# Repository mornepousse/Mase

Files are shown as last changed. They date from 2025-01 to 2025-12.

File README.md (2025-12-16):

# Mase
 Custom esp32 mouse.
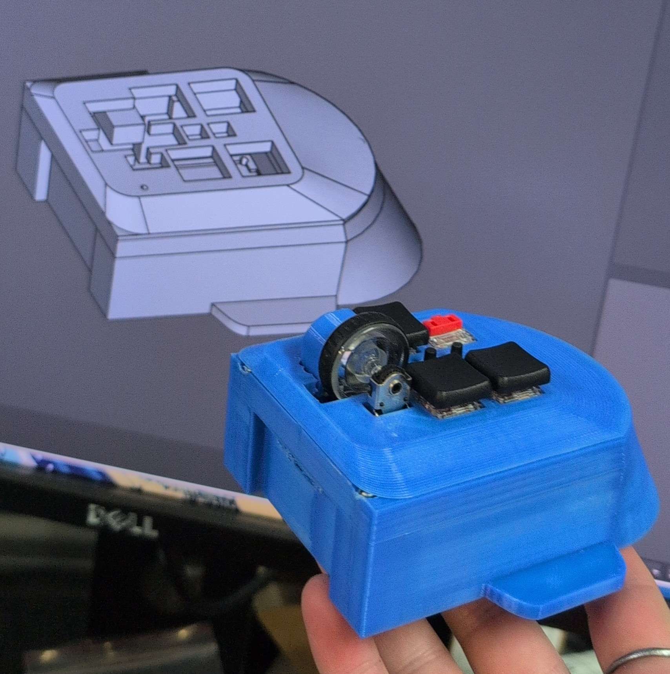
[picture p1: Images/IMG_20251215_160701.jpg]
Front PCB
 
 |index|References|Value|Footprint|Quantity|
 |:-|:--------|:-|:--|:-|
|1| C101, C102, C106, C108, C110    |0.1u|C_0805_2012Metric|5|
|2| C103, C105, C107, C109, C111    |1u|C_0805_2012Metric|5|
|3| C104                            |4.7u|C_0805_2012Metric     |1|
|4| R102, R103, R104                |10k|R_0805_2012Metric|3|
|5| R107, R108, R109                |?|R_0805_2012Metric|3|
|6| R105, R106                      |R_1206|R_0805_2012Metric|2|
|7| R101|39|R_0805_2012Metric|1|
|8| D101, D102|LED_3mm|LED_D3.0mm|2|
|9| U1|ESP32-S3-WROOM-1|ESP32-S3-WROOM-1|1|
|10|U2|PMW3360|PMW3360|1|
|11|U4|	TLV73333PDBV|	SOT-23-5	|1|
|12|U103|	TCR2EF19|	SOT-23-5	|1|
|13|SW1, SW2|	Push_Button|	SW_Hotswap_Kailh_Choc_V1V2_1.00u	|2|
|14|SW101, SW104|	Push_Button|	SW_Micro_Switch	|2|
|15|SW103, SW106|	Push_Button|	SW_Push_1P1T_NO_CK_KSC7xxJ	|2|
|16|SW3|	RotaryEncoder_Switch_MP|	RollerEncoder_Panasonic_EVQWGD001	|1|
|17|	SW102|	Push_Button|Switch_Toggle_SPDT_SubMini	|1|
|18|TP101, TP102, TP103, TP104, TP105, TP106, TP107|TestPoint|TestPoint_Pad_D1.0mm|7|
|19|	H1, H2, H3, H4|	MountingHole|MountingHole_3.2mm_M3|4|
|20|	Brd101|	SSD1306|	128x64OLED	|1|
|21|	J1|	Conn_01x04|	PinHeader_1x04_P2.54mm_Vertical	|1|
|22|	J2|	Conn_02x04_Counter_Clockwise|IDC-Header_2x04_P2.54mm_Vertical|1|
|23|	J101|	Conn_02x03_Counter_Clockwise|	Harwin_Gecko-G125-FVX0605L0X_2x03_P1.25mm_Vertical	|1|

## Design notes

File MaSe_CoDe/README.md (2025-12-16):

# MaSe - Mouse Sensor Firmware

**MaSe** est un firmware de souris haute performance pour l'ESP32-S3, utilisant le capteur optique PMW3389 et l'interface TinyUSB pour une communication HID rapide.

## 🚀 Fonctionnalités

*   **Capteur PMW3389** : Support complet via SPI avec lecture en mode "Burst" pour une latence minimale.
*   **Polling Rate 1000Hz** : Boucle principale et tick FreeRTOS optimisés pour une réponse à 1ms.
*   **DPI Ajustable** : Cycle entre les niveaux de DPI (400, 800, 1600, 3200, 6400) via un bouton dédié.
*   **Molette de défilement** : Support d'encodeur rotatif.
*   **Boutons Programmables** : Clic gauche, droit, milieu, et touches de fonction (ex: Touche Windows).
*   **Indicateur d'État LED** : LED WS2812 (RGB) pour indiquer le mode de connexion (Vert = USB).
*   **Architecture Modulaire** : Code séparé pour le capteur, la gestion des LEDs et la logique principale.

## 🛠 Matériel Requis

*   **Microcontrôleur** : ESP32-S3 (Testé sur DevKitM-1 / DevKitC).
*   **Capteur** : PixArt PMW3389.
*   **Composants** : Switchs pour les boutons, Encodeur rotatif, LED WS2812.

### 🔌 Pinout (Configuration par défaut)

| Périphérique | Fonction | GPIO (ESP32-S3) |
| :--- | :--- | :--- |
| **PMW3389** | MISO | 7 |
| | MOSI | 6 |
| | SCLK | 5 |
| | CS | 15 |
| | MOTION | 4 |
| **Boutons** | Clic Gauche (LMB) | 21 |
| | Clic Droit (RMB) | 37 |
| | Clic Molette (Middle) | 38 |
| | DPI Switch | 44 |
| | Touche Windows | 35 |
| **Encodeur** | A | 2 |
| | B | 42 |
| | C (Commun/GND) | 41 |
| **LED** | Data (WS2812) | 48 |

## 📂 Structure du Projet

```
main/
├── main.c           # Point d'entrée, boucle principale (USB, lecture capteur)
├── pmw3389.c        # Driver du capteur (SPI, Burst read, SROM)
├── pmw3389.h        # Définitions et prototypes du capteur
├── led_status.c     # Gestion de la LED d'état (RMT)
├── led_status.h     # Prototypes LED
├── srom_pmw3389.h   # Firmware binaire du capteur
└── CMakeLists.txt   # Configuration de build
```

## 🔨 Compilation et Flash

Ce projet utilise le framework **ESP-IDF**.

1.  **Configurer la cible :**
    ```bash
    idf.py set-target esp32s3
    ```

2.  **Compiler :**
    ```bash
    idf.py build
    ```

3.  **Flasher et Monitorer :**
    ```bash
    idf.py -p /dev/ttyACM0 flash monitor
    ```

## 📝 Notes

*   Le firmware du capteur (SROM) est chargé au démarrage. Assurez-vous que le fichier `srom_pmw3389.h` est présent.
*   La fréquence FreeRTOS est configurée à 1000Hz pour assurer la fluidité du curseur.

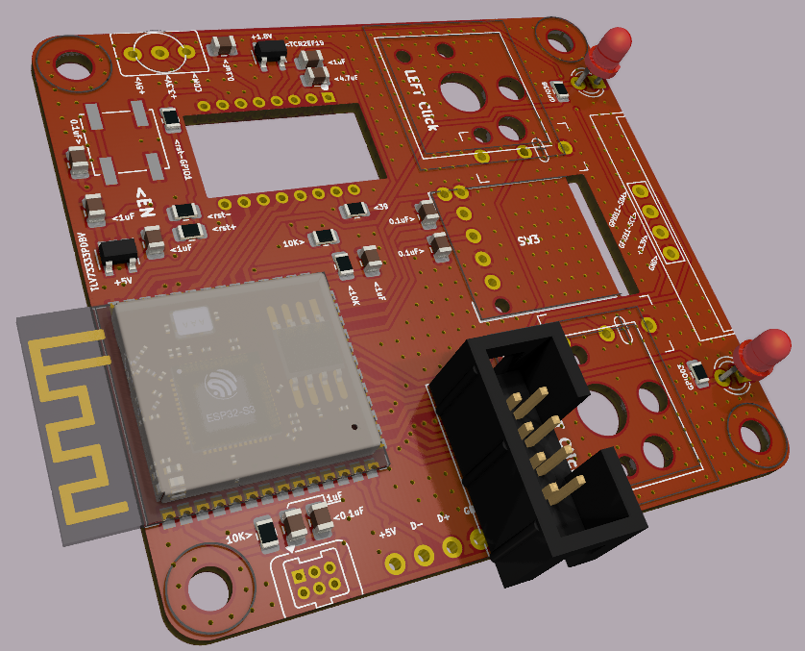
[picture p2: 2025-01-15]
Images/front.png

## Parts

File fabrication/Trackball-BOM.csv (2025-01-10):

Comment | Designator | Footprint | LCSC
0.1u | C11 | Capacitor_SMD:C_0603_1608Metric | C14663
1u | C12 | Capacitor_SMD:C_0603_1608Metric | C15849
4.7u | C14 | Capacitor_SMD:C_0402_1005Metric | C23733
1u | C10,C13,C15,C16 | Capacitor_SMD:C_0402_1005Metric | C52923
30p | C18,C19 | Capacitor_SMD:C_0402_1005Metric | C1570
100n | C1,C2,C3,C4,C5,C6,C7,C8,C9,C17 | Capacitor_SMD:C_0402_1005Metric | C1525
MountingHole | H1,H2,H3,H4 | MountingHole:MountingHole_3.2mm_M3
Conn_01x04 | J1 | Connector_PinHeader_2.54mm:PinHeader_1x04_P2.54mm_Vertical
Conn_02x10_Odd_Even | J2 | Connector_PinHeader_2.54mm:PinHeader_2x10_P2.54mm_Vertical
39 | R1 | Resistor_SMD:R_0402_1005Metric | C25110
27 | R3,R4 | Resistor_SMD:R_0402_1005Metric | C138021
10k | R2,R5 | Resistor_SMD:R_0402_1005Metric | C25744
1k | R6,R7 | Resistor_SMD:R_0402_1005Metric | C11702
SW_Push | SW1,SW2 | Button_Switch_SMD:SW_SPST_Omron_B3FS-100xP | C271750
TCR2EF19 | U1 | Package_TO_SOT_SMD:SOT-23-5 | C146366
PMW3360 | U2 | PMW3360:PMW3360
RP2040 | U3 | RP2040:RP2040-QFN-56 | C2040
TLV73333PDBV | U4 | Package_TO_SOT_SMD:SOT-23-5 | C134139
W25Q128JVS | U5 | Package_SO:SOIC-8_5.23x5.23mm_P1.27mm | C97521
Crystal_GND24 | Y1 | Crystal:Crystal_SMD_3225-4Pin_3.2x2.5mm | C9002

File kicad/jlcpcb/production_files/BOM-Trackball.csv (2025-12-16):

Comment | Designator | Footprint | LCSC | Quantity
TLV73333PDBV | U3 | SOT-23-5 | C134139 | 1
0.1u | C1,C5,C6,C7,C9 | C_0805_2012Metric | C14663 | 5
1u | C2 | C_0805_2012Metric | C15849 | 1
10uF | C8 | C_0805_2012Metric_Pad1.18x1.45mm_HandSolder | C15850 | 1
TP4056 | U5 | SOIC-8-1EP_3.9x4.9mm_P1.27mm_EP2.29x3mm | C16581 | 1
100 | R8 | R_0805_2012Metric_Pad1.20x1.40mm_HandSolder | C17408 | 1
10k | R1,R102,R2,R5 | R_0805_2012Metric | C17414 | 4
1k | R3,R4,R6 | R_0805_2012Metric | C17513 | 3
0R | R7 | R_1206_3216Metric_Pad1.30x1.75mm_HandSolder | C17888 | 1
4.7u | C104 | C_0805_2012Metric | C23733 | 1
39 | R101 | R_0805_2012Metric | C25110 | 1
TCR2EF19 | U1 | SOT-23-5 | C2862411 | 1
DW01 | U6 | SOT-23-6_Handsoldering | C2927799 | 1
1u | C3,C4 | C_0805_2012Metric | C52923 | 2
FS8205A | U7 | SOT-23-6_Handsoldering | C908265 | 1

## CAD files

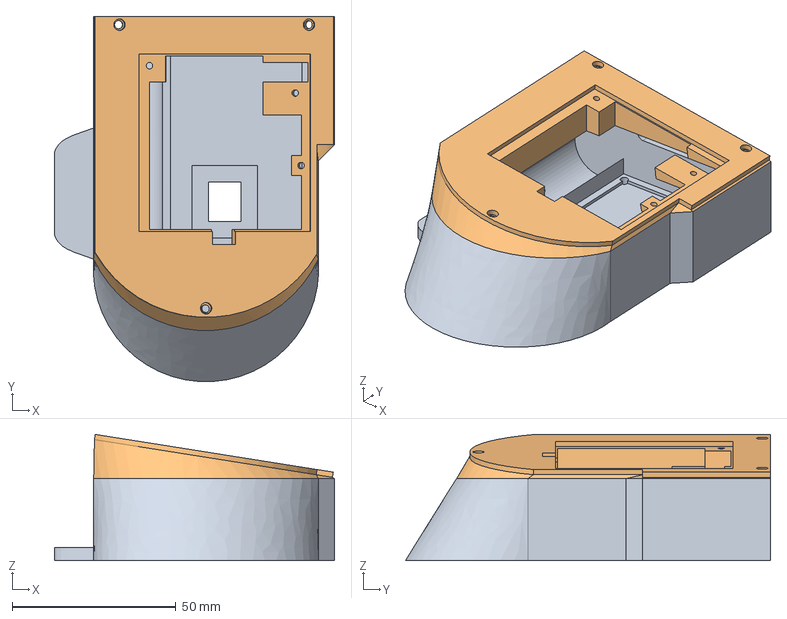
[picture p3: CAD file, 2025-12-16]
fabrication/Unnamed1.FCStd
85.5 x 111.3 x 38.5 mm
Base
supportTopPCB

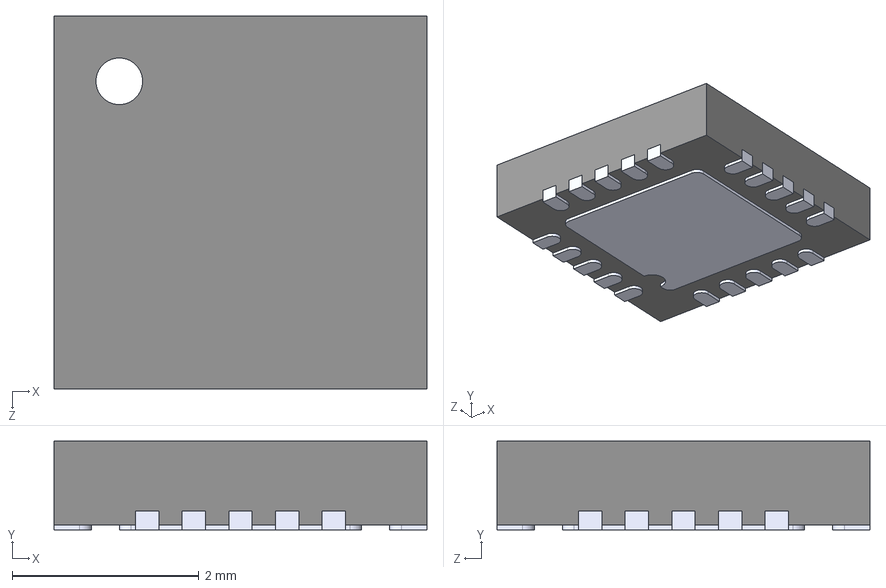
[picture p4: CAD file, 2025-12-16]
kicad/NRF24L01_/NRF24L01_.step
4.00 x 0.95 x 4.00 mm

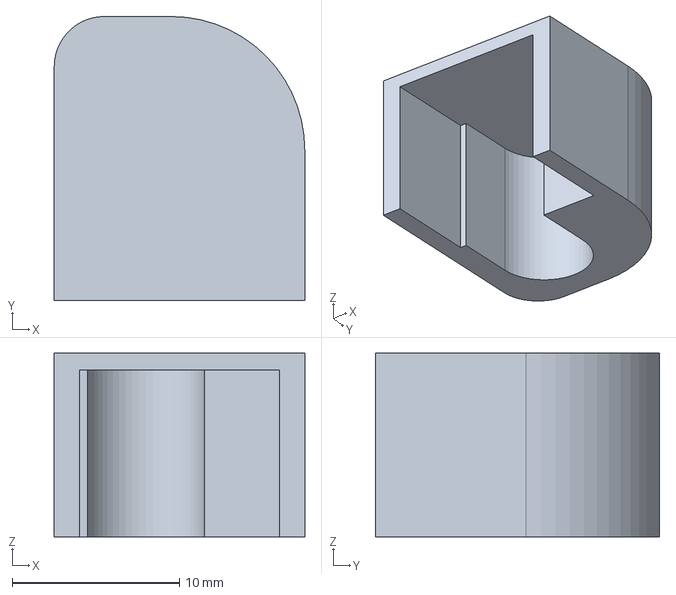
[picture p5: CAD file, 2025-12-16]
fabrication/piecemolette.FCStd
15.0 x 17.0 x 11.0 mm

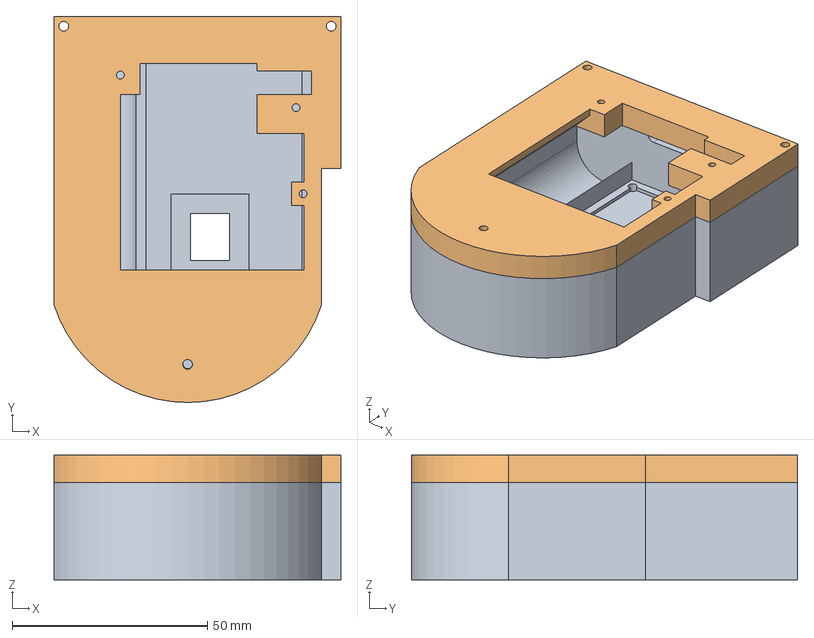
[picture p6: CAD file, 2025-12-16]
fabrication/mase.FCStd
73.5 x 98.9 x 32.0 mm

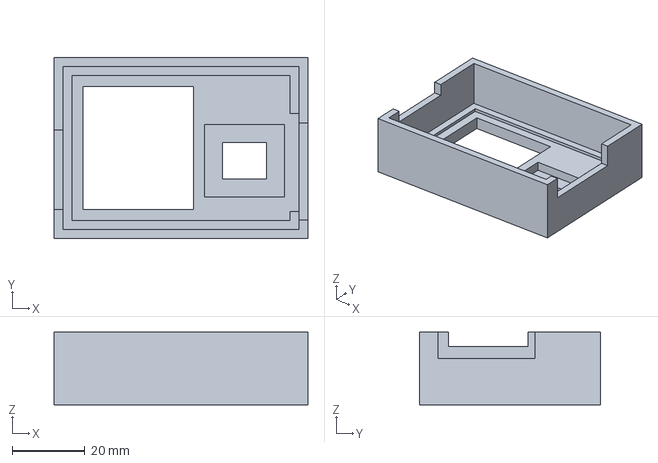
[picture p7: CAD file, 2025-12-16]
fabrication/Unnamed.FCStd
70.0 x 50.0 x 20.0 mm

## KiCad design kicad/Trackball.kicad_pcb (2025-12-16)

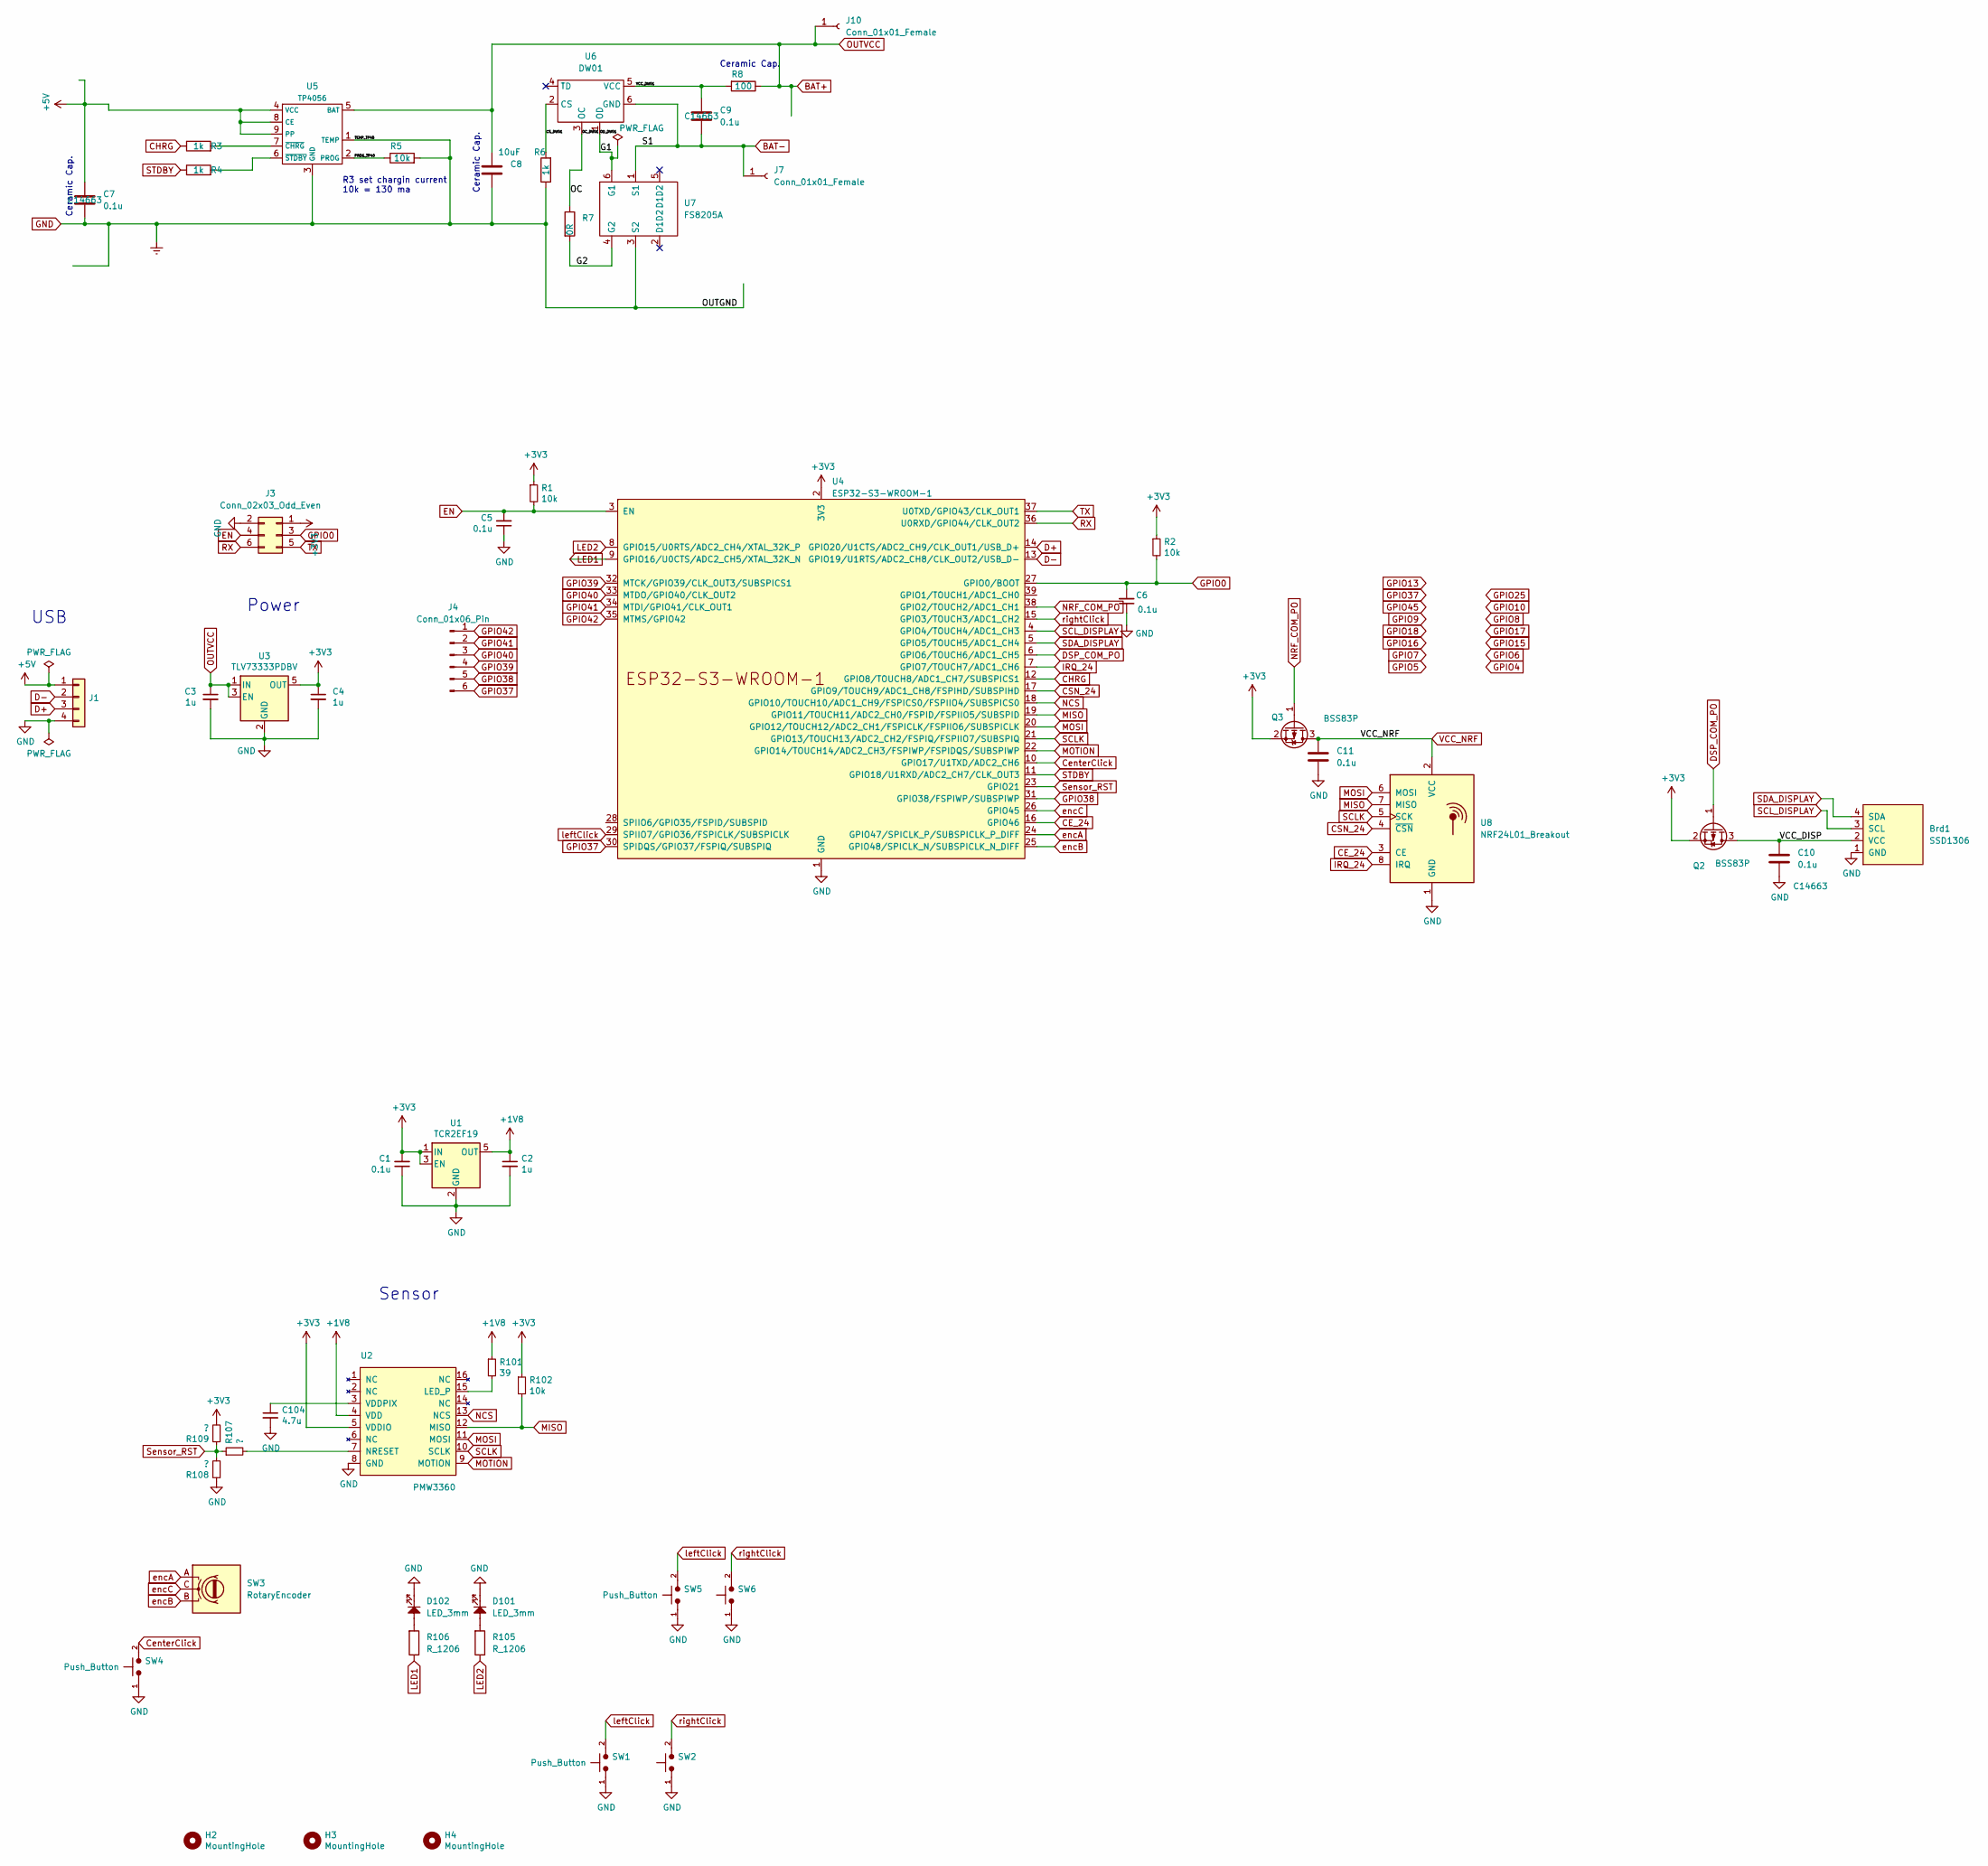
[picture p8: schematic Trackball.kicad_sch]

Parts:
Brd1: SSD1306; PinHeader_1x04_P2.54mm_Vertical
C1, C5, C6, C7, C9, C10, C11: 0.1u; C_0805_2012Metric; LCSC C14663
C2: 1u; C_0805_2012Metric; LCSC C15849
C3, C4: 1u; C_0805_2012Metric; LCSC C52923
C8: 10uF; C_0805_2012Metric_Pad1.18x1.45mm_HandSolder
C104: 4.7u; C_0805_2012Metric; LCSC C23733
D101, D102: LED_3mm; LED_D3.0mm
H2, H3, H4: MountingHole; MountingHole_3.2mm_M3
J1: Conn_01x04; PinHeader_1x04_P2.54mm_Vertical
J3: Conn_02x03_Odd_Even; Harwin_Gecko-G125-FVX0605L0X_2x03_P1.25mm_Vertical
J4: Conn_01x06_Pin; PinHeader_1x06_P2.00mm_Vertical
J7, J10: Conn_01x01_Female; PinSocket_1x01_P2.54mm_Vertical
Q2, Q3: BSS83P; SOT-23
R1, R2, R102: 10k; R_0805_2012Metric; LCSC C25744
R3, R4, R6: 1k; R_0805_2012Metric
R5: 10k; R_0805_2012Metric
R7: 0R; R_1206_3216Metric_Pad1.30x1.75mm_HandSolder
R8: 100; R_0805_2012Metric_Pad1.20x1.40mm_HandSolder
R101: 39; R_0805_2012Metric; LCSC C25110
R105, R106: R_1206; R_0805_2012Metric
R107, R108, R109: ?; R_0805_2012Metric; LCSC C25110
SW1, SW2: Push_Button; SW_Hotswap_Kailh_Choc_V1V2_1.00u
SW3: RotaryEncoder; Alps-EC10E1220501
SW4, SW5, SW6: Push_Button; SW_Micro_Switch
U1: TCR2EF19; SOT-23-5; LCSC C146366
U2: PMW3360
U3: TLV73333PDBV; SOT-23-5; LCSC C134139
U4: ESP32-S3-WROOM-1
U5: TP4056; SOIC-8-1EP_3.9x4.9mm_P1.27mm_EP2.29x3mm
U6: DW01; SOT-23-6_Handsoldering
U7: FS8205A; SOT-23-6_Handsoldering
U8: NRF24L01_Breakout; nRF24L01_Breakout

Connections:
+1V8: C2.1, R101.1, U1.5 (OUT), U2.4 (VDD)
+3V3: C1.2, C4.1, J3.1, Q2.2 (S), Q3.2 (S), R1.1, R2.1, R102.1, R109.2, U1.1 (IN), U1.3 (EN), U2.5 (VDDIO), U3.5 (OUT), U4.2 (3V3)
+5V: C7.1, J1.1, U5.4 (VCC), U5.8 (CE), U5.9 (PP)
/CS_DW01: R6.2, U6.2 (CS)
/G1: U6.1 (OD), U7.6 (G1)
/G2: R7.2, U7.4 (G2)
/OC: R7.1, U6.3 (OC)
/PROG_TP40: R5.1, U5.2 (PROG)
/VCC_DISP: Brd1.2 (VCC), C10.1, Q2.3 (D)
/VCC_DW01: C9.1, R8.2, U6.5 (VCC)
BAT+: C3.1, C8.1, J10.1, R8.1, U3.1 (IN), U3.3 (EN), U5.5 (BAT)
BAT-: C9.2, J7.1, U6.6 (GND), U7.1 (S1)
CE_24: U4.16 (GPIO46), U8.3 (CE)
CHRG: R3.1, U4.12 (GPIO8/TOUCH8/ADC1_CH7/SUBSPICS1)
CSN_24: U4.17 (GPIO9/TOUCH9/ADC1_CH8/FSPIHD/SUBSPIHD), U8.4 (~CSN)
CenterClick: SW4.2, U4.10 (GPIO17/U1TXD/ADC2_CH6)
D+: J1.3, U4.14 (GPIO20/U1CTS/ADC2_CH9/CLK_OUT1/USB_D+)
D-: J1.2, U4.13 (GPIO19/U1RTS/ADC2_CH8/CLK_OUT2/USB_D-)
DSP_COM_PO: Q2.1 (G), U4.6 (GPIO6/TOUCH6/ADC1_CH5)
EN: C5.2, J3.4, R1.2, U4.3 (EN)
GND: Brd1.1 (GND), C1.1, C2.2, C3.2, C4.2, C5.1, C6.1, C7.2, C8.2, C10.2, C11.2, C104.2, D101.1, D102.1, J1.4, J3.2, R5.2, R6.1, R108.1, SW1.1, SW2.1, SW4.1, SW5.1, SW6.1, U1.2 (GND), U2.8 (GND), U3.2 (GND), U4.1 (GND), U4.40 (GND), U4.41 (GND), U5.1 (TEMP), U5.3 (GND), U7.3 (S2), U8.1 (GND)
GPIO0: C6.2, J3.3, R2.2, U4.27 (GPIO0/BOOT)
GPIO37: J4.6, U4.30 (SPIDQS/GPIO37/FSPIQ/SUBSPIQ)
GPIO38: J4.5, U4.31 (GPIO38/FSPIWP/SUBSPIWP)
GPIO39: J4.4, U4.32 (MTCK/GPIO39/CLK_OUT3/SUBSPICS1)
GPIO40: J4.3, U4.33 (MTDO/GPIO40/CLK_OUT2)
GPIO41: J4.2, U4.34 (MTDI/GPIO41/CLK_OUT1)
GPIO42: J4.1, U4.35 (MTMS/GPIO42)
IRQ_24: U4.7 (GPIO7/TOUCH7/ADC1_CH6), U8.8 (IRQ)
LED1: R106.2, U4.9 (GPIO16/U0CTS/ADC2_CH5/XTAL_32K_N)
LED2: R105.2, U4.8 (GPIO15/U0RTS/ADC2_CH4/XTAL_32K_P)
MISO: R102.2, U2.12 (MISO), U4.19 (GPIO11/TOUCH11/ADC2_CH0/FSPID/FSPIIO5/S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), U8.7 (MISO)
MOSI: U2.11 (MOSI), U4.20 (GPIO12/TOUCH12/ADC2_CH1/FSPICLK/FSPIIO6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), U8.6 (MOSI)
MOTION: U2.9 (MOTION), U4.22 (GPIO14/TOUCH14/ADC2_CH3/FSPIWP/FSPIDQS/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)
NCS: U2.13 (NCS), U4.18 (GPIO10/TOUCH10/ADC1_CH9/FSPICS0/FSPIIO4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)
NRF_COM_PO: Q3.1 (G), U4.38 (GPIO2/TOUCH2/ADC1_CH1)
unnamed: D101.2, R105.1
unnamed: D102.2, R106.1
unnamed: R101.2, U2.15 (LED_P)
unnamed: R107.2, U2.7 (NRESET)
unnamed: C104.1, U2.3 (VDDPIX)
unnamed: R3.2, U5.7 (~CHRG)
unnamed: R4.2, U5.6 (~STDBY)
RX: J3.6, U4.36 (U0RXD/GPIO44/CLK_OUT2)
SCLK: U2.10 (SCLK), U4.21 (GPIO13/TOUCH13/ADC2_CH2/FSPIQ/FSPIIO7/S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), U8.5 (SCK)
SCL_DISPLAY: Brd1.3 (SCL), U4.4 (GPIO4/TOUCH4/ADC1_CH3)
SDA_DISPLAY: Brd1.4 (SDA), U4.5 (GPIO5/TOUCH5/ADC1_CH4)
STDBY: R4.1, U4.11 (GPIO18/U1RXD/ADC2_CH7/CLK_OUT3)
Sensor_RST: R107.1, R108.2, R109.1, U4.23 (GPIO21)
TX: J3.5, U4.37 (U0TXD/GPIO43/CLK_OUT1)
VCC_NRF: C11.1, Q3.3 (D), U8.2 (VCC)
encA: SW3.A, U4.24 (GPIO47/SPICLK_P/SUBSPICLK_P_DIFF)
encB: SW3.B, U4.25 (GPIO48/SPICLK_N/SUBSPICLK_N_DIFF)
encC: SW3.C, U4.26 (GPIO45)
leftClick: SW1.2, SW5.2, U4.29 (SPIIO7/GPIO36/FSPICLK/SUBSPICLK)
rightClick: SW2.2, SW6.2, U4.15 (GPIO3/TOUCH3/ADC1_CH2)

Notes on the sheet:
Ceramic Cap.
R3 set chargin current 10k = 130 ma
Power
Sensor
USB

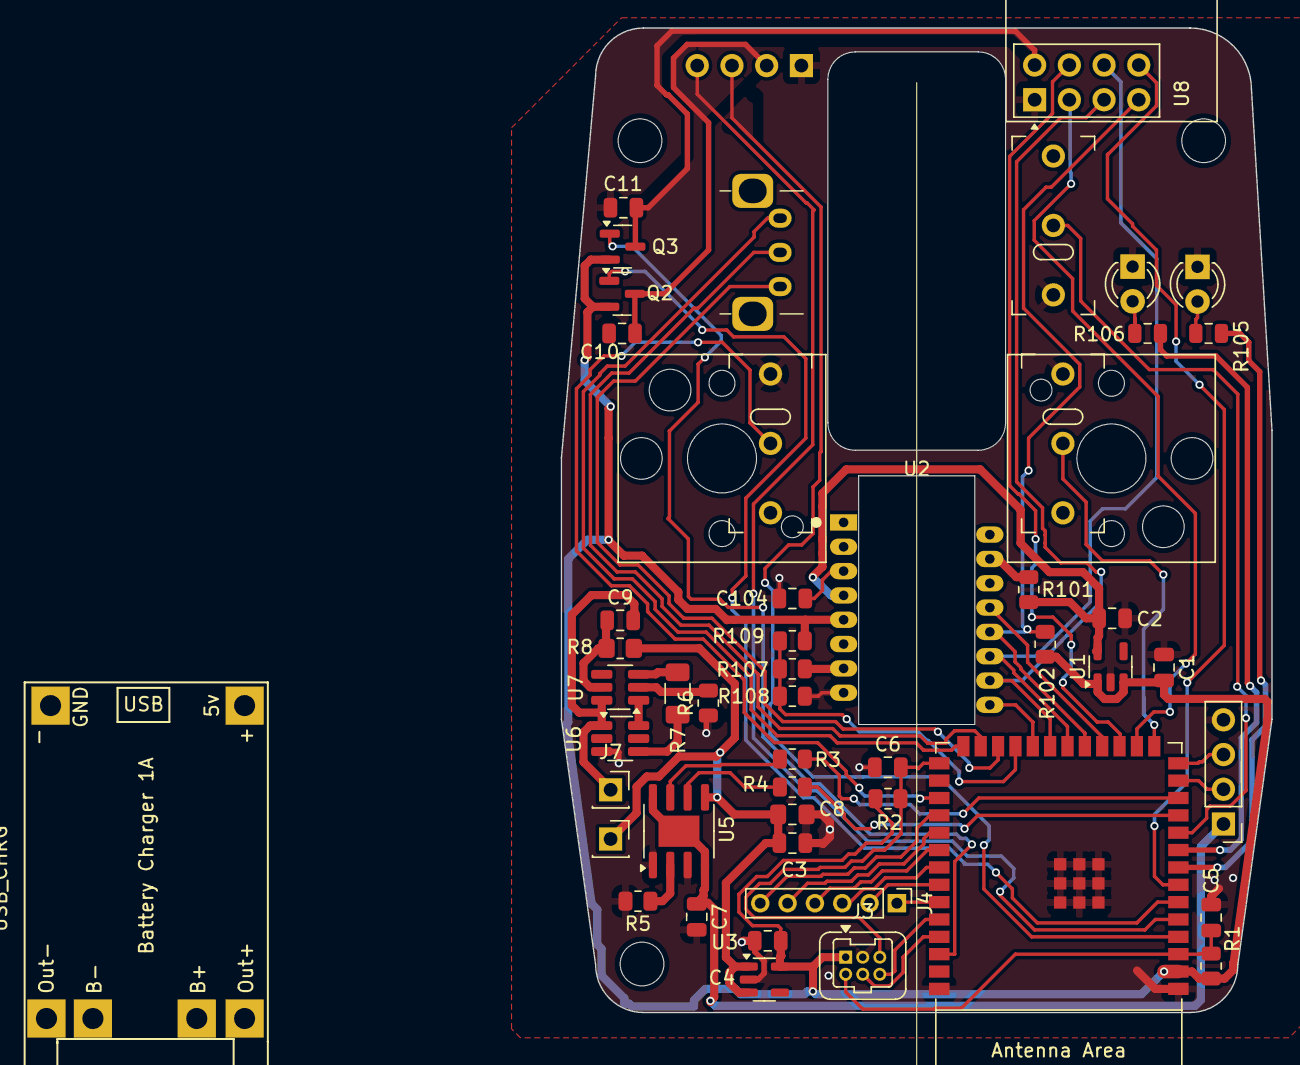
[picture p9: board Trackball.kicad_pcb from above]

Board: 2 copper layers, 52.0 x 72.0 mm, 55 parts (1 on the bottom side), 56 nets.

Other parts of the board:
USB_CHRG**: TP4056-18650

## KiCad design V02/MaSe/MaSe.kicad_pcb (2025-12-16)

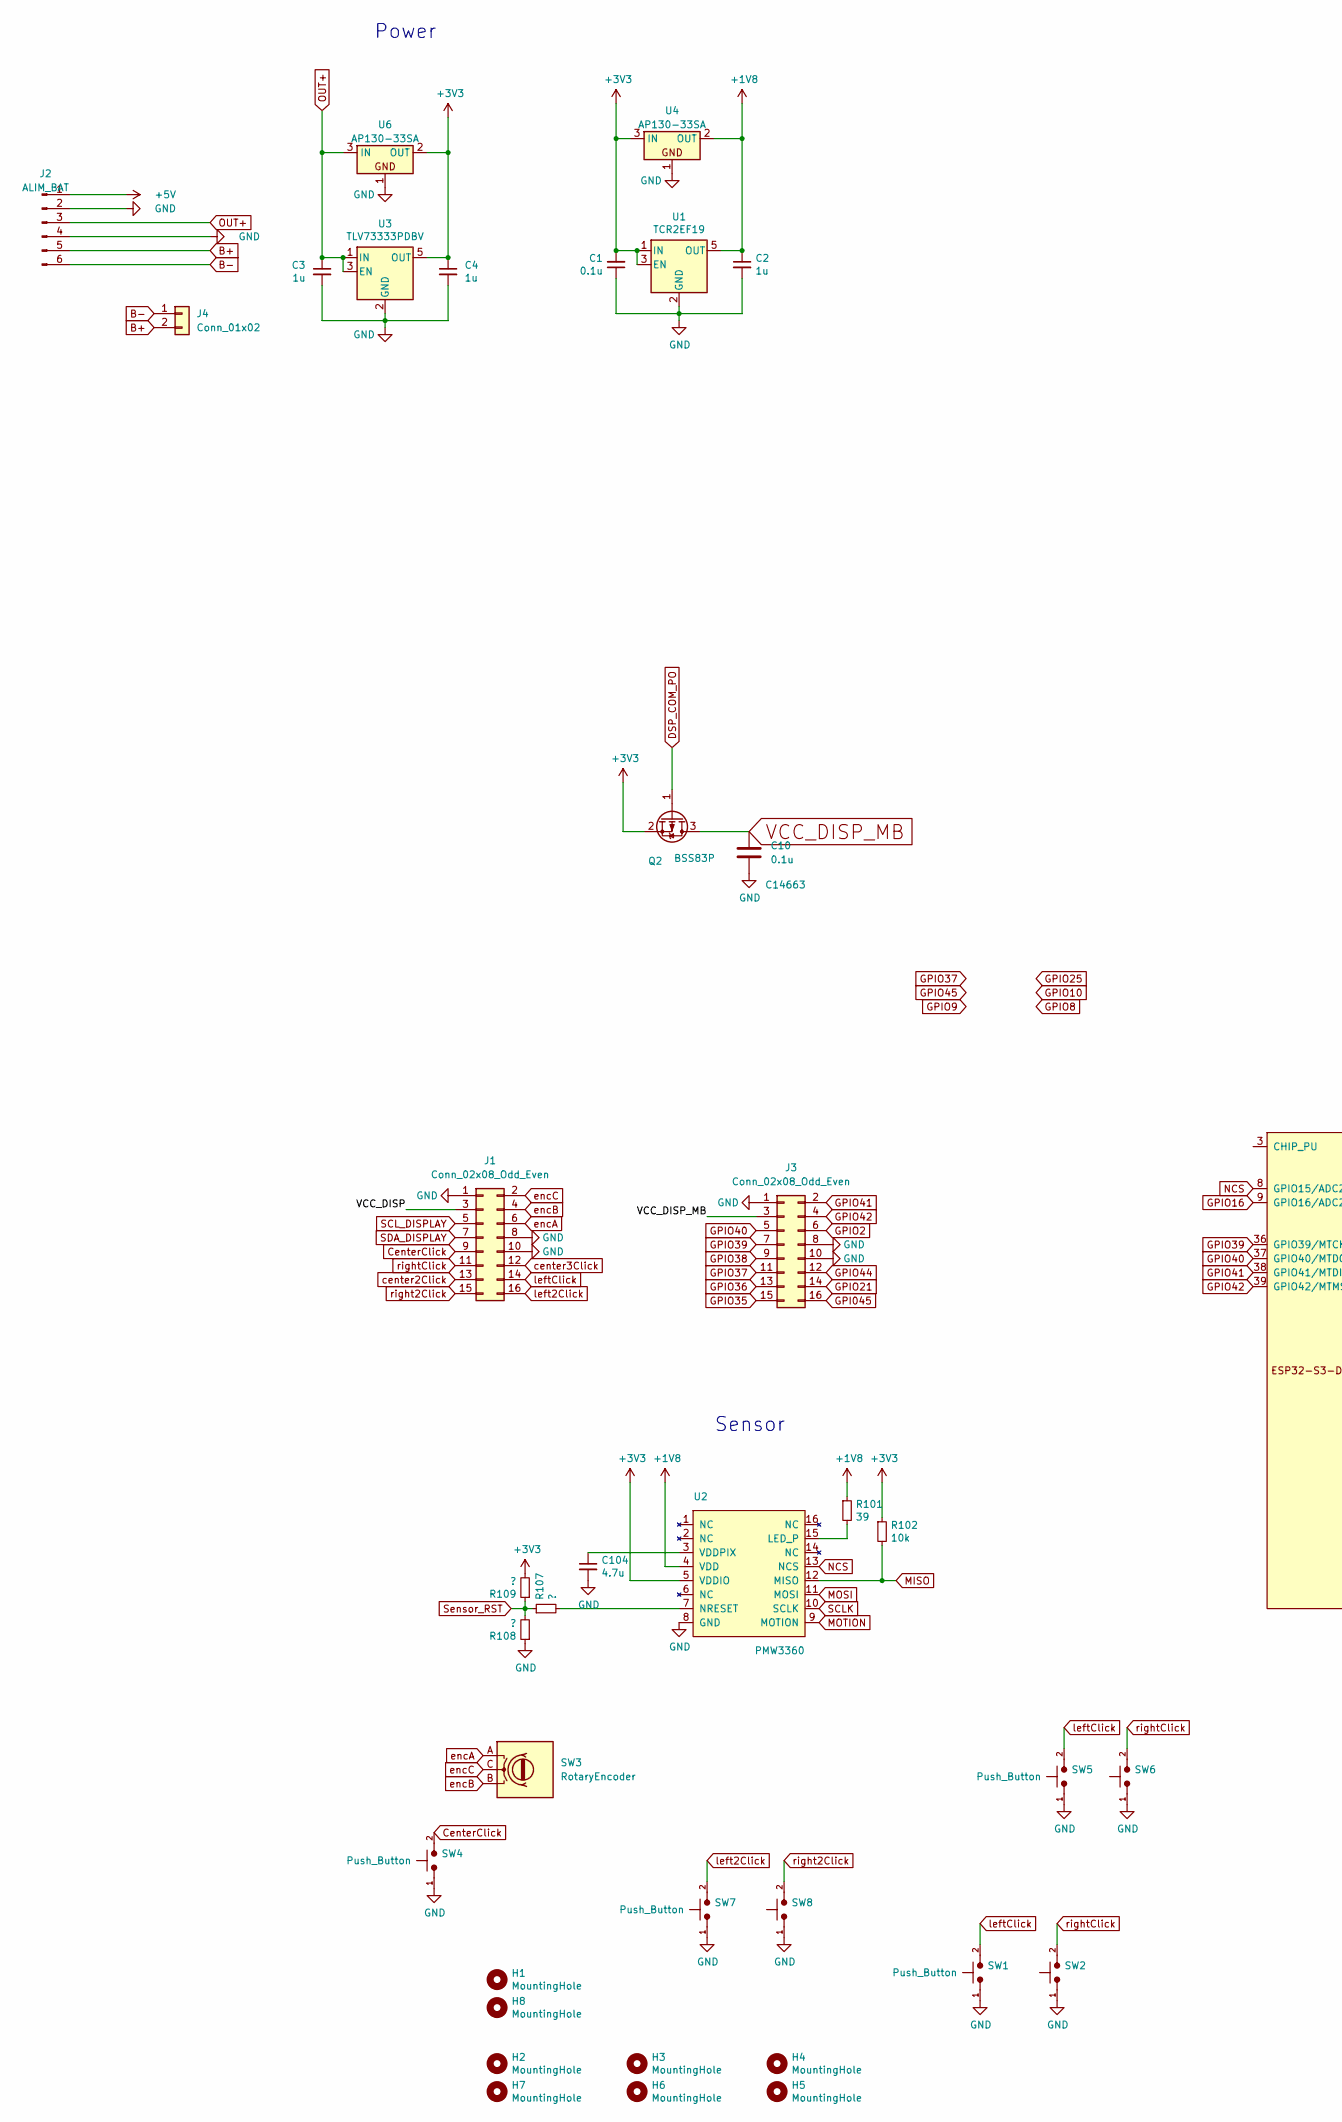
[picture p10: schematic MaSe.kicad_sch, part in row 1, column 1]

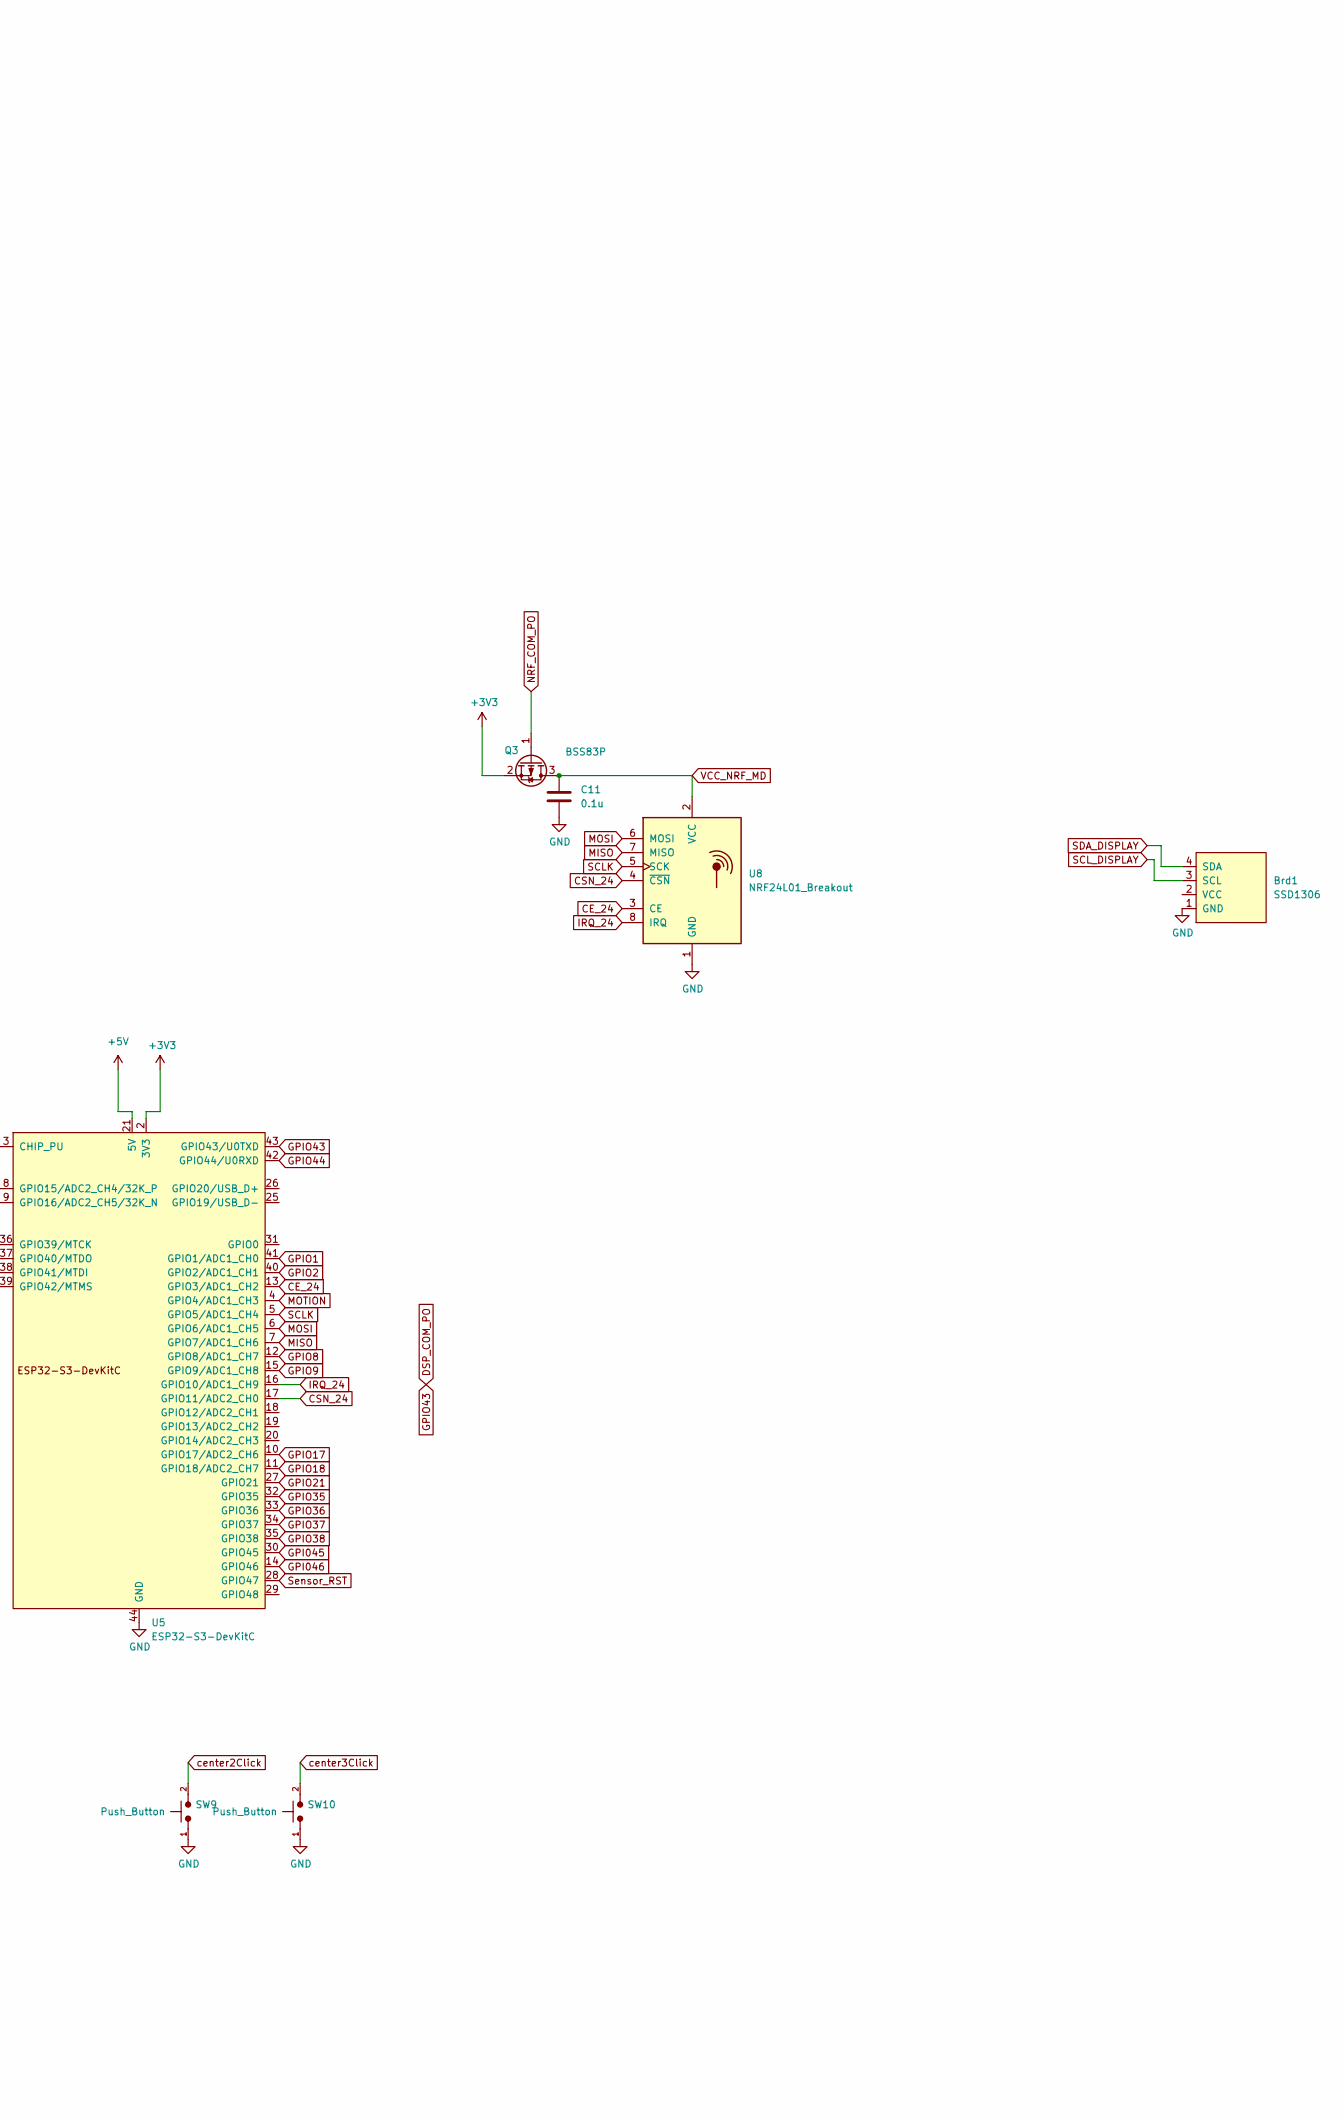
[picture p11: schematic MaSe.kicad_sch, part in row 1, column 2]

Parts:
Brd1: SSD1306; PinHeader_1x04_P2.54mm_Vertical
C1, C10, C11: 0.1u; C_0805_2012Metric; LCSC C14663
C2: 1u; C_0805_2012Metric; LCSC C15849
C3, C4: 1u; C_0805_2012Metric; LCSC C52923
C104: 4.7u; C_0805_2012Metric; LCSC C23733
H1, H2, H3, H4, H5, H6, H7, H8: MountingHole; MountingHole_2.2mm_M2_ISO14580
J1, J3: Conn_02x08_Odd_Even; PinHeader_2x08_P1.27mm_Vertical
J2: ALIM_BAT; TP4056-18650
J4: Conn_01x02; PinHeader_1x02_P2.54mm_Vertical
Q2, Q3: BSS83P; SOT-23
R101: 39; R_0805_2012Metric; LCSC C25110
R102: 10k; R_0805_2012Metric; LCSC C25744
R107, R108, R109: ?; R_0805_2012Metric; LCSC C25110
SW1, SW2, SW7, SW8: Push_Button; SW_Hotswap_Kailh_Choc_V1V2_1.00u
SW3: RotaryEncoder; Alps-EC10E1220501
SW4, SW5, SW6: Push_Button; SW_Micro_Switch
SW9, SW10: Push_Button; SW_PUSH_6mm
U1: TCR2EF19; SOT-23-5; LCSC C146366
U2: PMW3360
U3: TLV73333PDBV; SOT-23-5; LCSC C134139
U4, U6: AP130-33SA; SOT-23
U5: ESP32-S3-DevKitC
U8: NRF24L01_Breakout; nRF24L01_Breakout

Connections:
+1V8: C2.1, R101.1, U1.5 (OUT), U2.4 (VDD), U4.2 (OUT)
+3V3: C1.2, C4.1, Q2.2 (S), Q3.2 (S), R102.1, R109.2, U1.1 (IN), U1.3 (EN), U2.5 (VDDIO), U3.5 (OUT), U4.3 (IN), U5.1 (3V3), U5.2 (3V3), U6.2 (OUT)
+5V: J2.1, U5.21 (5V)
/VCC_DISP: J1.3
B+: J2.5, J4.2
B-: J2.6, J4.1
CE_24: U5.13 (GPIO3/ADC1_CH2), U8.3 (CE)
CSN_24: U5.17 (GPIO11/ADC2_CH0), U8.4 (~CSN)
CenterClick: J1.9, SW4.2
DSP_COM_PO: Q2.1 (G), U5.43 (GPIO43/U0TXD)
GND: Brd1.1 (GND), C1.1, C2.2, C3.2, C4.2, C10.2, C11.2, C104.2, J1.1, J1.8, J1.10, J2.2, J2.4, J3.1, J3.8, J3.10, R108.1, SW1.1, SW2.1, SW4.1, SW5.1, SW6.1, SW7.1, SW8.1, SW9.1, SW10.1, U1.2 (GND), U2.8 (GND), U3.2 (GND), U4.1, U5.22 (GND), U5.23 (GND), U5.24 (GND), U5.44 (GND), U6.1, U8.1 (GND)
GPI045: J3.16, U5.30 (GPIO45)
GPI046: U5.14 (GPIO46)
GPIO1: U5.41 (GPIO1/ADC1_CH0)
GPIO2: J3.6, U5.40 (GPIO2/ADC1_CH1)
GPIO8: U5.12 (GPIO8/ADC1_CH7)
GPIO9: U5.15 (GPIO9/ADC1_CH8)
GPIO16: U5.9 (GPIO16/ADC2_CH5/32K_N)
GPIO17: U5.10 (GPIO17/ADC2_CH6)
GPIO18: U5.11 (GPIO18/ADC2_CH7)
GPIO21: J3.14, U5.27 (GPIO21)
GPIO35: J3.15, U5.32 (GPIO35)
GPIO36: J3.13, U5.33 (GPIO36)
GPIO37: J3.11, U5.34 (GPIO37)
GPIO38: J3.9, U5.35 (GPIO38)
GPIO39: J3.7, U5.36 (GPIO39/MTCK)
GPIO40: J3.5, U5.37 (GPIO40/MTDO)
GPIO41: J3.2, U5.38 (GPIO41/MTDI)
GPIO42: J3.4, U5.39 (GPIO42/MTMS)
GPIO44: J3.12, U5.42 (GPIO44/U0RXD)
IRQ_24: U5.16 (GPIO10/ADC1_CH9), U8.8 (IRQ)
MISO: R102.2, U2.12 (MISO), U5.7 (GPIO7/ADC1_CH6), U8.7 (MISO)
MOSI: U2.11 (MOSI), U5.6 (GPIO6/ADC1_CH5), U8.6 (MOSI)
MOTION: U2.9 (MOTION), U5.4 (GPIO4/ADC1_CH3)
NCS: U2.13 (NCS), U5.8 (GPIO15/ADC2_CH4/32K_P)
NRF_COM_PO: Q3.1 (G)
unnamed: R101.2, U2.15 (LED_P)
unnamed: R107.2, U2.7 (NRESET)
unnamed: C104.1, U2.3 (VDDPIX)
OUT+: C3.1, J2.3, U3.1 (IN), U3.3 (EN), U6.3 (IN)
SCLK: U2.10 (SCLK), U5.5 (GPIO5/ADC1_CH4), U8.5 (SCK)
SCL_DISPLAY: Brd1.3 (SCL), J1.5
SDA_DISPLAY: Brd1.4 (SDA), J1.7
Sensor_RST: R107.1, R108.2, R109.1, U5.28 (GPIO47)
VCC_DISP_MB: C10.1, J3.3, Q2.3 (D)
VCC_NRF_MD: C11.1, Q3.3 (D), U8.2 (VCC)
center2Click: J1.13, SW9.2
center3Click: J1.12, SW10.2
encA: J1.6, SW3.A
encB: J1.4, SW3.B
encC: J1.2, SW3.C
left2Click: J1.16, SW7.2
leftClick: J1.14, SW1.2, SW5.2
right2Click: J1.15, SW8.2
rightClick: J1.11, SW2.2, SW6.2

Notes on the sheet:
Power
Sensor

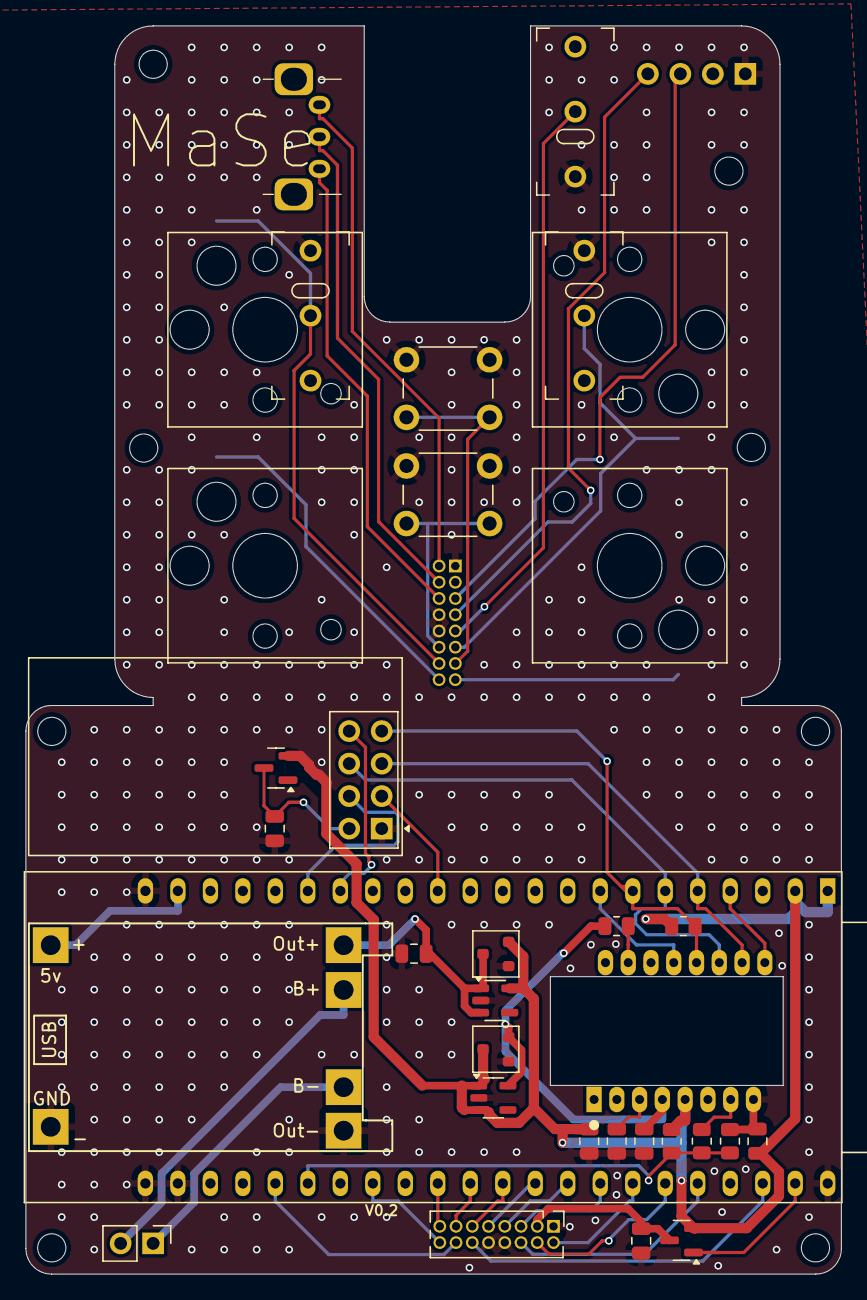
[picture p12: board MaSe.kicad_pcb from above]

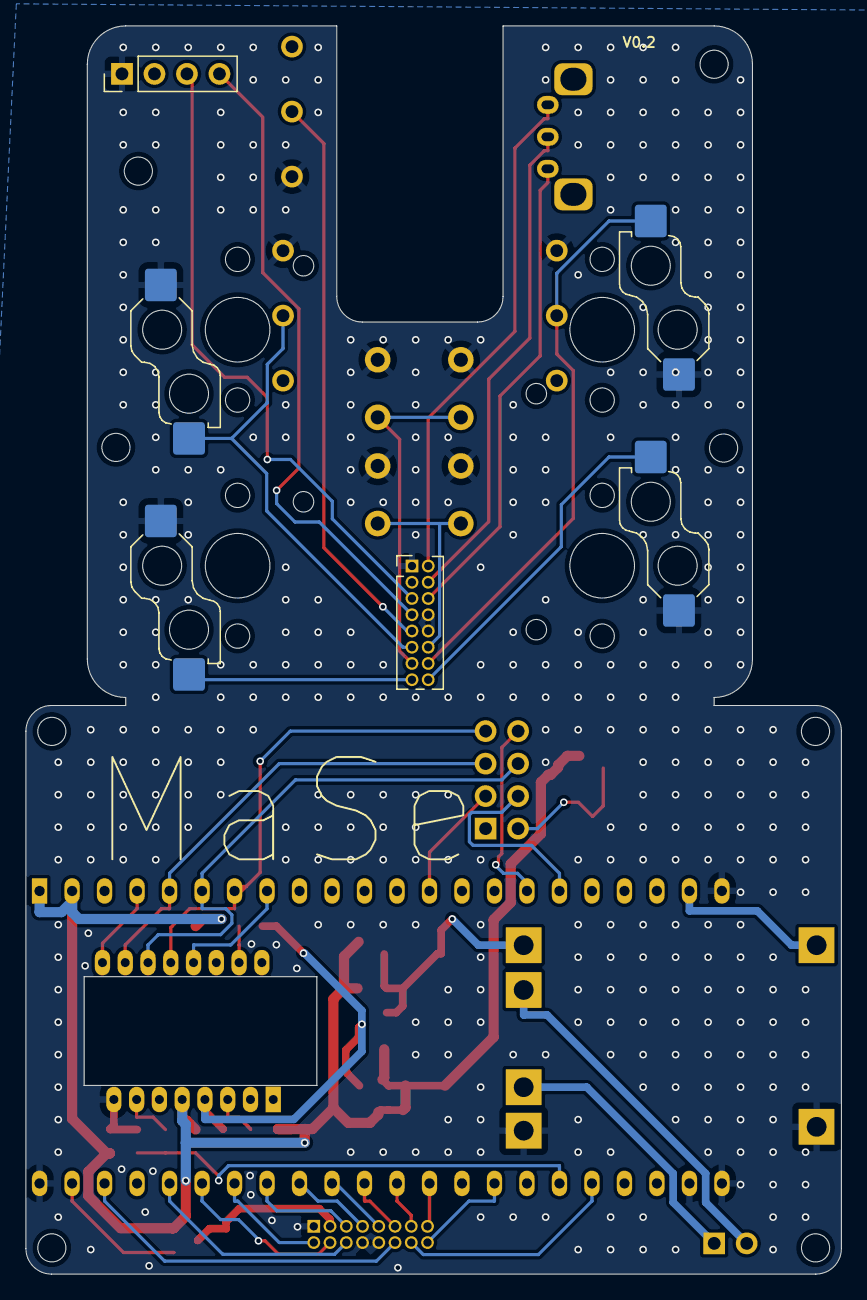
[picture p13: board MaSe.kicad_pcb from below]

Board: 2 copper layers, 63.8 x 97.6 mm, 44 parts (2 on the bottom side), 46 nets.

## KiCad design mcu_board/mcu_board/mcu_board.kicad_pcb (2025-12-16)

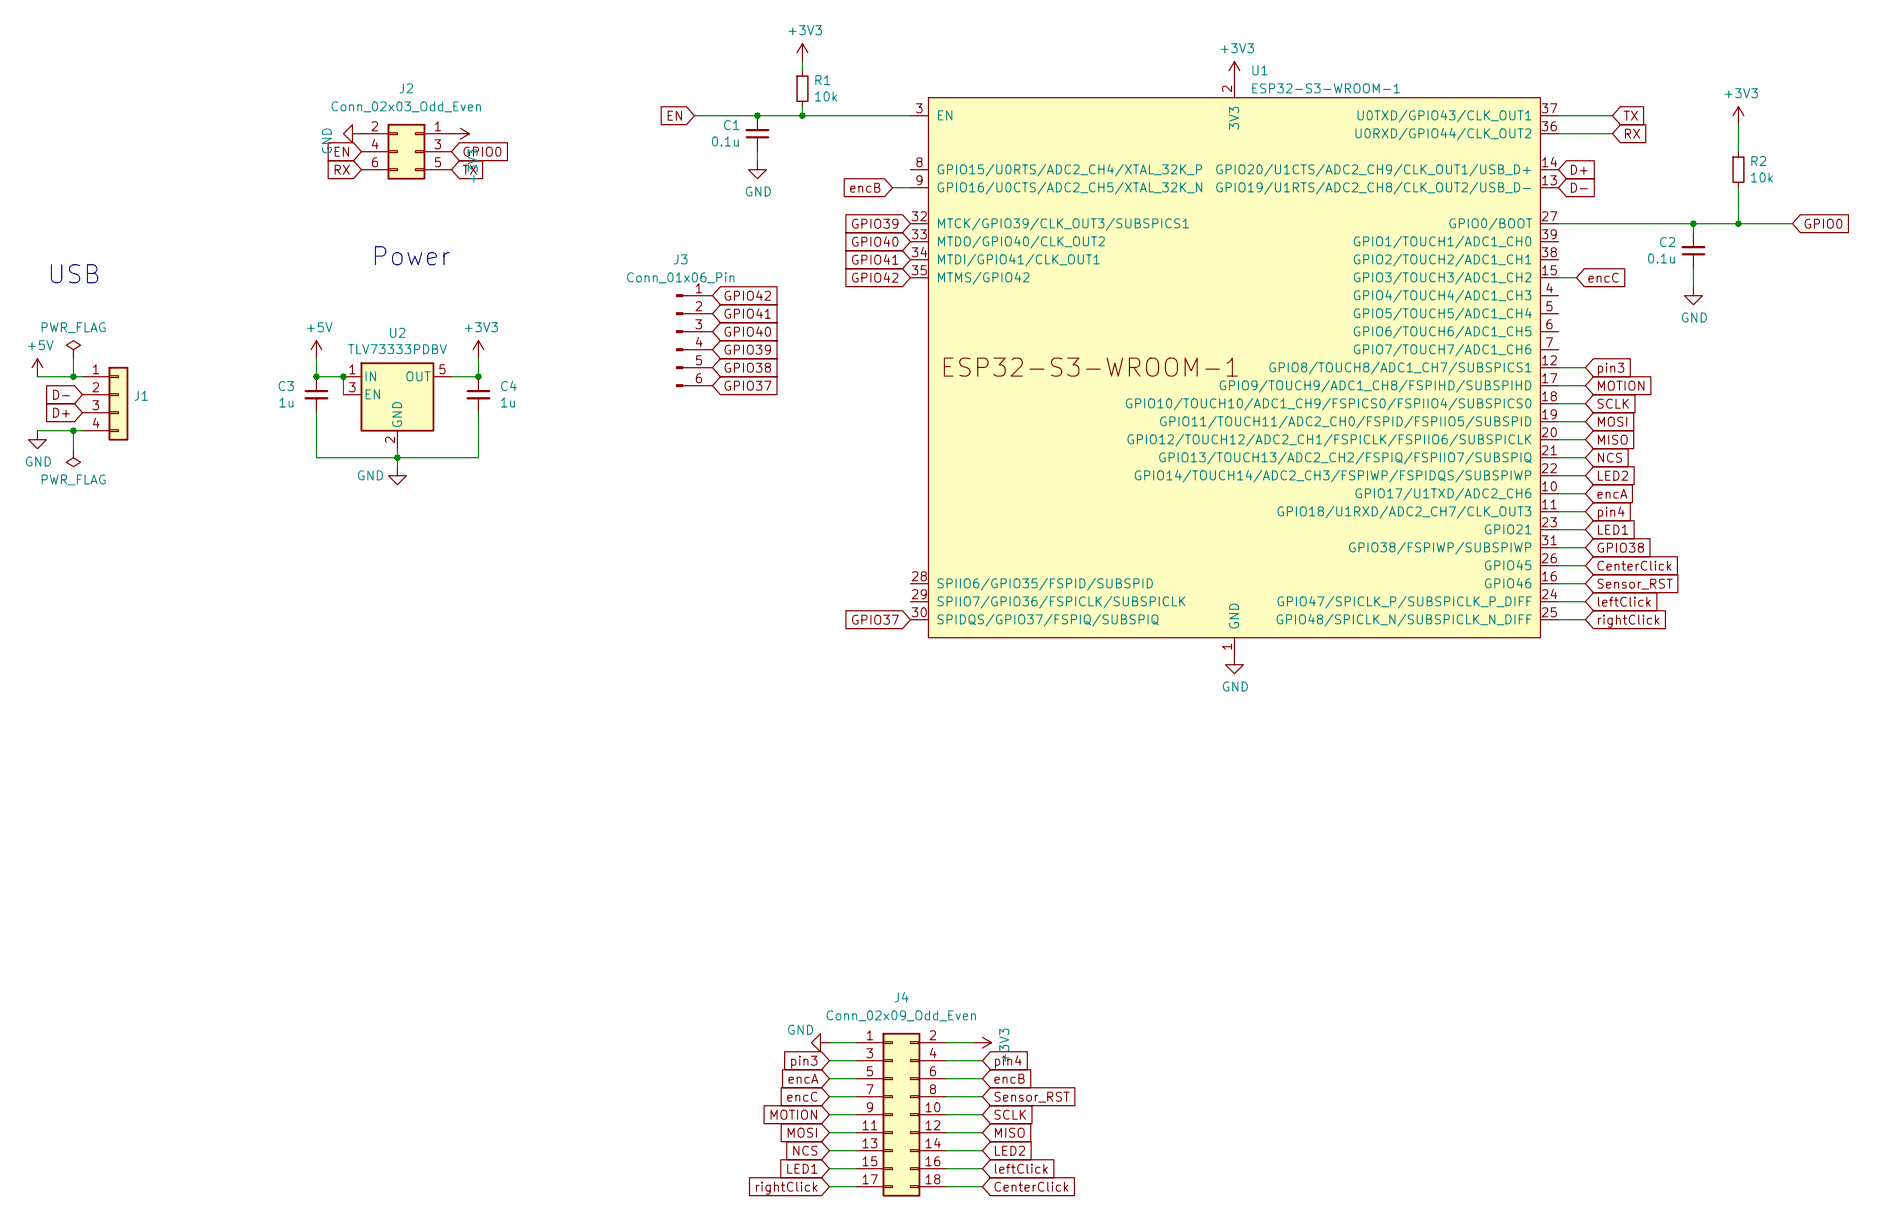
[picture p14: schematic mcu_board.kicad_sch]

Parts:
C1, C2: 0.1u; C_0805_2012Metric; LCSC C14663
C3, C4: 1u; C_0805_2012Metric; LCSC C52923
J1: Conn_01x04; PinHeader_1x04_P2.54mm_Vertical
J2: Conn_02x03_Odd_Even; Harwin_Gecko-G125-FVX0605L0X_2x03_P1.25mm_Vertical
J3: Conn_01x06_Pin; PinHeader_1x06_P2.00mm_Vertical
J4: Conn_02x09_Odd_Even; PinHeader_2x09_P2.54mm_Vertical
R1, R2: 10k; R_0805_2012Metric; LCSC C25744
U1: ESP32-S3-WROOM-1
U2: TLV73333PDBV; SOT-23-5; LCSC C134139

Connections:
+3V3: C4.1, J2.1, J4.2, R1.1, R2.1, U1.2 (3V3), U2.5 (OUT)
+5V: C3.1, J1.1, U2.1 (IN), U2.3 (EN)
CenterClick: J4.18, U1.26 (GPIO45)
D+: J1.3, U1.14 (GPIO20/U1CTS/ADC2_CH9/CLK_OUT1/USB_D+)
D-: J1.2, U1.13 (GPIO19/U1RTS/ADC2_CH8/CLK_OUT2/USB_D-)
EN: C1.2, J2.4, R1.2, U1.3 (EN)
GND: C1.1, C2.1, C3.2, C4.2, J1.4, J2.2, J4.1, U1.1 (GND), U1.40 (GND), U1.41 (GND), U2.2 (GND)
GPIO0: C2.2, J2.3, R2.2, U1.27 (GPIO0/BOOT)
GPIO37: J3.6, U1.30 (SPIDQS/GPIO37/FSPIQ/SUBSPIQ)
GPIO38: J3.5, U1.31 (GPIO38/FSPIWP/SUBSPIWP)
GPIO39: J3.4, U1.32 (MTCK/GPIO39/CLK_OUT3/SUBSPICS1)
GPIO40: J3.3, U1.33 (MTDO/GPIO40/CLK_OUT2)
GPIO41: J3.2, U1.34 (MTDI/GPIO41/CLK_OUT1)
GPIO42: J3.1, U1.35 (MTMS/GPIO42)
LED1: J4.15, U1.23 (GPIO21)
LED2: J4.14, U1.22 (GPIO14/TOUCH14/ADC2_CH3/FSPIWP/FSPIDQS/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)
MISO: J4.12, U1.20 (GPIO12/TOUCH12/ADC2_CH1/FSPICLK/FSPIIO6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)
MOSI: J4.11, U1.19 (GPIO11/TOUCH11/ADC2_CH0/FSPID/FSPIIO5/S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)
MOTION: J4.9, U1.17 (GPIO9/TOUCH9/ADC1_CH8/FSPIHD/SUBSPIHD)
NCS: J4.13, U1.21 (GPIO13/TOUCH13/ADC2_CH2/FSPIQ/FSPIIO7/S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)
RX: J2.6, U1.36 (U0RXD/GPIO44/CLK_OUT2)
SCLK: J4.10, U1.18 (GPIO10/TOUCH10/ADC1_CH9/FSPICS0/FSPIIO4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)
Sensor_RST: J4.8, U1.16 (GPIO46)
TX: J2.5, U1.37 (U0TXD/GPIO43/CLK_OUT1)
encA: J4.5, U1.10 (GPIO17/U1TXD/ADC2_CH6)
encB: J4.6, U1.9 (GPIO16/U0CTS/ADC2_CH5/XTAL_32K_N)
encC: J4.7, U1.15 (GPIO3/TOUCH3/ADC1_CH2)
leftClick: J4.16, U1.24 (GPIO47/SPICLK_P/SUBSPICLK_P_DIFF)
pin3: J4.3, U1.12 (GPIO8/TOUCH8/ADC1_CH7/SUBSPICS1)
pin4: J4.4, U1.11 (GPIO18/U1RXD/ADC2_CH7/CLK_OUT3)
rightClick: J4.17, U1.25 (GPIO48/SPICLK_N/SUBSPICLK_N_DIFF)

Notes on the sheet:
Power
USB

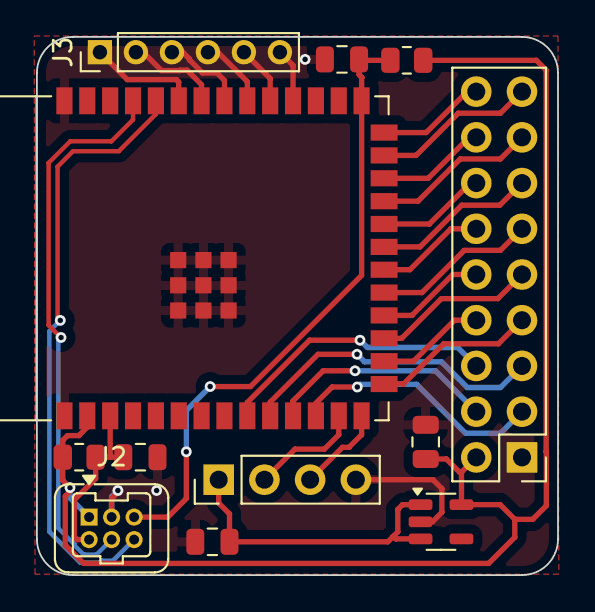
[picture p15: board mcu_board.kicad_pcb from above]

Board: 2 copper layers, 28.9 x 29.9 mm, 12 parts (0 on the bottom side), 31 nets.

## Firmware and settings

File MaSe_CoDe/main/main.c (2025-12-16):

/* Blink Example

   This example code is in the Public Domain (or CC0 licensed, at your option.)

   Unless required by applicable law or agreed to in writing, this
   software is distributed on an "AS IS" BASIS, WITHOUT WARRANTIES OR
   CONDITIONS OF ANY KIND, either express or implied.
*/
#include <stdio.h>
#include <string.h>
#include "freertos/FreeRTOS.h"
#include "freertos/task.h"
#include "esp_log.h"
#include "esp_system.h"
#include "esp_err.h"
#include "pmw3389.h"
#include "led_status.h"
#include "esp_rom_sys.h"
#include "esp_timer.h"
#include "tinyusb.h"
#include "tinyusb_default_config.h"
#include "class/hid/hid_device.h"
#include "driver/gpio.h"
// #include "esp_rom"

static const char *TAG = "Main";



#define PIN_LMB 21
#define PIN_RMB 37
#define PIN_CENTER_FUNCT_1_CLICK 36
#define PIN_CENTER_FUNCT_2_CLICK 44
//#define PIN_RIGHT_CLICK 37
#define PIN_RIGHT_FUNCT_CLICK 35
//#define PIN_LEFT_CLICK 21
#define PIN_LEFT_FUNCT_CLICK 45
#define PIN_MIDDLE_CLICK 38

#define PIN_ENCODER_A 2
#define PIN_ENCODER_B 42
#define PIN_ENCODER_C 41

static void encoder_init(void)
{
    gpio_config_t io_conf = {};
    // A and B as inputs with pull-up
    io_conf.intr_type = GPIO_INTR_DISABLE;
    io_conf.mode = GPIO_MODE_INPUT;
    io_conf.pin_bit_mask = (1ULL << PIN_ENCODER_A) | (1ULL << PIN_ENCODER_B);
    io_conf.pull_down_en = 0;
    io_conf.pull_up_en = 1;
    gpio_config(&io_conf);

    // C as output low (Common Ground)
    io_conf.mode = GPIO_MODE_OUTPUT;
    io_conf.pin_bit_mask = (1ULL << PIN_ENCODER_C);
    io_conf.pull_up_en = 0;
    gpio_config(&io_conf);
    gpio_set_level(PIN_ENCODER_C, 0);
}

static int8_t encoder_read_scroll(void)
{
    static const int8_t table[16] = {0, 1, -1, 0, -1, 0, 0, 1, 1, 0, 0, -1, 0, -1, 1, 0};
    static uint8_t last_ab = 0;
    static int8_t accum = 0;
    
    uint8_t curr_ab = (gpio_get_level(PIN_ENCODER_A) << 1) | gpio_get_level(PIN_ENCODER_B);
    uint8_t idx = (last_ab << 2) | curr_ab;
    last_ab = curr_ab;
    
    accum += table[idx];
    
    // Assuming 2 steps per detent. Adjust if needed (e.g. 4 or 1).
    if (accum >= 2) {
        accum -= 2;
        return -1;
    } else if (accum <= -2) {
        accum += 2;
        return 1;
    }
    return 0;
}

static void buttons_init(void)
{
    gpio_config_t io_conf = {};
    io_conf.intr_type = GPIO_INTR_DISABLE;
    io_conf.mode = GPIO_MODE_INPUT;
    io_conf.pin_bit_mask = (1ULL << PIN_LMB) | (1ULL << PIN_RMB) | (1ULL << PIN_MIDDLE_CLICK) |
                           (1ULL << PIN_CENTER_FUNCT_1_CLICK) | (1ULL << PIN_CENTER_FUNCT_2_CLICK)   
                           | (1ULL << PIN_RIGHT_FUNCT_CLICK) | (1ULL << PIN_LEFT_FUNCT_CLICK);
    io_conf.pull_down_en = 0;
    io_conf.pull_up_en = 1;
    gpio_config(&io_conf);
}

static uint8_t buttons_read(void)
{
    uint8_t buttons = 0;
    if (gpio_get_level(PIN_LMB) == 0) buttons |= TU_BIT(0);
    if (gpio_get_level(PIN_RMB) == 0) buttons |= TU_BIT(1);
    if (gpio_get_level(PIN_MIDDLE_CLICK) == 0) buttons |= TU_BIT(2);
    //if (gpio_get_level(PIN_LEFT_CLICK) == 0) buttons |= TU_BIT(3);
    //.if (gpio_get_level(PIN_RIGHT_CLICK) == 0) buttons |= TU_BIT(4);
    return buttons;
}












#define EPNUM_CDC_NOTIF 1
#define EPNUM_CDC_IN 2
#define EPNUM_CDC_OUT 2
#define EPNUM_VENDOR_IN 5
#define EPNUM_VENDOR_OUT 5
#define EPNUM_KEYBOARD 4
#define EPNUM_MOUSE 6

#define TUSB_DESC_TOTAL_LEN (TUD_CONFIG_DESC_LEN + 1 * TUD_HID_DESC_LEN)

/**
 * @brief HID report descriptor
 *
 * In this example we implement Keyboard + Mouse HID device,
 * so we must define both report descriptors
 */
const uint8_t hid_report_descriptor[] = {
    TUD_HID_REPORT_DESC_KEYBOARD(HID_REPORT_ID(HID_ITF_PROTOCOL_KEYBOARD)),
    TUD_HID_REPORT_DESC_MOUSE(HID_REPORT_ID(HID_ITF_PROTOCOL_MOUSE))};

/**
 * @brief String descriptor
 */
const char *hid_string_descriptor[5] = {
    // array of pointer to string descriptors
    (char[]){0x09, 0x04},    // 0: is supported language is English (0x0409)
    "MornePousse",               // 1: Manufacturer
    "MaSe",        // 2: Product
    "123256",                // 3: Serials, should use chip ID
    "Mouse", // 4: HID
};

static const uint8_t hid_configuration_descriptor[] = {
    // Configuration number, interface count, string index, total length, attribute, power in mA
    TUD_CONFIG_DESCRIPTOR(1, 1, 0, TUSB_DESC_TOTAL_LEN, TUSB_DESC_CONFIG_ATT_REMOTE_WAKEUP, 100),

    // Interface number, string index, boot protocol, report descriptor len, EP In address, size & polling interval
    TUD_HID_DESCRIPTOR(0, 4, false, sizeof(hid_report_descriptor), 0x81, 16, 1),
};

/********* TinyUSB HID callbacks ***************/

// Invoked when received GET HID REPORT DESCRIPTOR request
// Application return pointer to descriptor, whose contents must exist long enough for transfer to complete
uint8_t const *tud_hid_descriptor_report_cb(uint8_t instance)
{
    // We use only one interface and one HID report descriptor, so we can ignore parameter 'instance'
    return hid_report_descriptor;
}

// Invoked when received GET_REPORT control request
// Application must fill buffer report's content and return its length.
// Return zero will cause the stack to STALL request
uint16_t tud_hid_get_report_cb(uint8_t instance, uint8_t report_id, hid_report_type_t report_type, uint8_t *buffer, uint16_t reqlen)
{
    (void)instance;
    (void)report_id;
    (void)report_type;
    (void)buffer;
    (void)reqlen;

    return 0;
}

// Invoked when received SET_REPORT control request or
// received data on OUT endpoint ( Report ID = 0, Type = 0 )
void tud_hid_set_report_cb(uint8_t instance, uint8_t report_id, hid_report_type_t report_type, uint8_t const *buffer, uint16_t bufsize)
{
}

/********* Application ***************/

/*
typedef enum
{
    MOUSE_DIR_RIGHT,
    MOUSE_DIR_DOWN,
    MOUSE_DIR_LEFT,
    MOUSE_DIR_UP,
    MOUSE_DIR_MAX,
} mouse_dir_t;

#define DISTANCE_MAX 125
#define DELTA_SCALAR 5
*/

/*
static void mouse_draw_square_next_delta(int8_t *delta_x_ret, int8_t *delta_y_ret)
{
    static mouse_dir_t cur_dir = MOUSE_DIR_RIGHT;
    static uint32_t distance = 0;

    // Calculate next delta
    if (cur_dir == MOUSE_DIR_RIGHT)
    {
        *delta_x_ret = DELTA_SCALAR;
        *delta_y_ret = 0;
    }
    else if (cur_dir == MOUSE_DIR_DOWN)
    {
        *delta_x_ret = 0;
        *delta_y_ret = DELTA_SCALAR;
    }
    else if (cur_dir == MOUSE_DIR_LEFT)
    {
        *delta_x_ret = -DELTA_SCALAR;
        *delta_y_ret = 0;
    }
    else if (cur_dir == MOUSE_DIR_UP)
    {
        *delta_x_ret = 0;
        *delta_y_ret = -DELTA_SCALAR;
    }

    // Update cumulative distance for current direction
    distance += DELTA_SCALAR;
    // Check if we need to change direction
    if (distance >= DISTANCE_MAX)
    {
        distance = 0;
        cur_dir++;
        if (cur_dir == MOUSE_DIR_MAX)
        {
            cur_dir = 0;
        }
    }
}
*/

/*
static void app_send_hid_demo(void)
{
    // Keyboard output: Send key 'a/A' pressed and released
    ESP_LOGI(TAG, "Sending Keyboard report");
    uint8_t keycode[6] = {HID_KEY_A};
    tud_hid_keyboard_report(HID_ITF_PROTOCOL_KEYBOARD, 0, keycode);
    vTaskDelay(pdMS_TO_TICKS(50));
    tud_hid_keyboard_report(HID_ITF_PROTOCOL_KEYBOARD, 0, NULL);

    // Mouse output: Move mouse cursor in square trajectory
    ESP_LOGI(TAG, "Sending Mouse report");
    int8_t delta_x;
    int8_t delta_y;
    for (int i = 0; i < (DISTANCE_MAX / DELTA_SCALAR) * 4; i++)
    {
        // Get the next x and y delta in the draw square pattern
        mouse_draw_square_next_delta(&delta_x, &delta_y);
        tud_hid_mouse_report(HID_ITF_PROTOCOL_MOUSE, 0x00, delta_x, delta_y, 0, 0);
        vTaskDelay(pdMS_TO_TICKS(20));
    }
}
*/



void app_main(void)
{
    ESP_LOGI(TAG, "USB initialization");
    tinyusb_config_t tusb_cfg = TINYUSB_DEFAULT_CONFIG(); 
    tusb_cfg.descriptor.full_speed_config = hid_configuration_descriptor;
    tusb_cfg.descriptor.string = hid_string_descriptor;
    tusb_cfg.descriptor.string_count = sizeof(hid_string_descriptor) / sizeof(hid_string_descriptor[0]);

    ESP_ERROR_CHECK(tinyusb_driver_install(&tusb_cfg));
    ESP_LOGI(TAG, "USB initialization DONE");

    xTaskCreate(led_task, "led_task", 2048, NULL, 5, NULL);

    pmw3389_init();

    buttons_init();
    encoder_init();

    pmw3389_selftest();

    // Ensuite tu peux garder une boucle de lecture continue
    // app_send_hid_demo();
    uint8_t last_buttons = 0;
    uint8_t last_dpi_btn = 1;
    uint8_t last_win_btn = 1;
    while (1)
    {
        vTaskDelay(pdMS_TO_TICKS(1));
        if (tud_mounted())
        {
            uint8_t burstBuffer[12];
            curTime = esp_timer_get_time();
            unsigned long elapsed = curTime - lastTS;
            // ESP_LOGI(TAG, "Elapsed since last burst: %lu ms", elapsed);
            if (!inBurst)
            {
                pmw3389_enable_burst_mode(); // start burst mode
                lastTS = curTime;
            }
            if (elapsed >= 1000)
            {
                pmw3389_read_burst(burstBuffer, 12);

                // DPI Button Check
                uint8_t dpi_btn = gpio_get_level(PIN_CENTER_FUNCT_2_CLICK);
                if (last_dpi_btn == 1 && dpi_btn == 0)
                {
                    pmw3389_cycle_dpi();
                }
                last_dpi_btn = dpi_btn;

                // Win Key Check
                uint8_t win_btn = gpio_get_level(PIN_RIGHT_FUNCT_CLICK);
                if (win_btn != last_win_btn)
                {
                    bool success = false;
                    if (win_btn == 0) {
                        success = tud_hid_keyboard_report(HID_ITF_PROTOCOL_KEYBOARD, KEYBOARD_MODIFIER_LEFTGUI, NULL);
                    } else {
                        success = tud_hid_keyboard_report(HID_ITF_PROTOCOL_KEYBOARD, 0, NULL);
                    }
                    if (success) {
                        last_win_btn = win_btn;
                    }
                }

                int motion = (burstBuffer[0] & 0x80) > 0;
                // int surface = (burstBuffer[0] & 0x08) > 0; // 0 if on surface / 1 if off surface

                int xl = burstBuffer[2];
                int xh = burstBuffer[3];
                int yl = burstBuffer[4];
                int yh = burstBuffer[5];

                // int squal = burstBuffer[6];

                int16_t x = (int16_t)(xh << 8 | xl);
                int16_t y = (int16_t)(yh << 8 | yl);

                dx -= x;
                dy -= y;
                // ESP_LOGI(TAG, "Burst read: motion=%d surface=%d dx=%d dy=%d squal=%d", motion, surface, dx, dy, squal);

                uint8_t buttons = buttons_read();
                int8_t scroll = encoder_read_scroll();

                if (motion || buttons != last_buttons || scroll != 0)
                {
                    // signed char mdx = constrain(dx, -127, 127);
                    // signed char mdy = constrain(dy, -127, 127);

                    // Mouse.move(mdx, mdy, 0);
                    // mouse_draw_square_next_delta(&dx, &dy);
                    // mouse_draw_square_next_delta(&dx, &dy);
                    
                    int8_t report_x = (dx > 127) ? 127 : ((dx < -127) ? -127 : dx);
                    int8_t report_y = (dy > 127) ? 127 : ((dy < -127) ? -127 : dy);

                    if (tud_hid_mouse_report(HID_ITF_PROTOCOL_MOUSE, buttons, report_x, report_y, scroll, 0))
                    {
                        dx -= report_x;
                        dy -= report_y;
                        last_buttons = buttons;
                    }
                }

                lastTS = curTime;
            }
        }
    }
}

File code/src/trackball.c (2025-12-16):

/* 
 * The MIT License (MIT)
 *
 * Copyright (c) 2021 Jacek Fedorynski
 * Copyright (c) 2019 Ha Thach (tinyusb.org)
 *
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
 */

#include <stdlib.h>
#include <stdio.h>
#include <string.h>

#include "bsp/board.h"
#include "tusb.h"

#include "pico/stdlib.h"

#include "hardware/gpio.h"

#include "pmw3360.h"

#define PIN_LMB 16
#define PIN_RMB 17
#define PIN_CENTER_FUNCT_1_CLICK 36
#define PIN_CENTER_FUNCT_2_CLICK 44
#define PIN_RIGHT_CLICK 37
#define PIN_RIGHT_FUNCT_CLICK 35
#define PIN_LEFT_CLICK 21
#define PIN_LEFT_FUNCT_CLICK 45
#define PIN_MIDDLE_CLICK 38

#define PIN_ENCODER_A 2
#define PIN_ENCODER_B 42
#define PIN_ENCODER_C 41

// These IDs are bogus. If you want to distribute any hardware using this,
// you will have to get real ones.
#define USB_VID 0xCAFE
#define USB_PID 0xBABA

tusb_desc_device_t const desc_device = {
    .bLength = sizeof(tusb_desc_device_t),
    .bDescriptorType = TUSB_DESC_DEVICE,
    .bcdUSB = 0x0200,
    .bDeviceClass = 0x00,
    .bDeviceSubClass = 0x00,
    .bDeviceProtocol = 0x00,
    .bMaxPacketSize0 = CFG_TUD_ENDPOINT0_SIZE,

    .idVendor = USB_VID,
    .idProduct = USB_PID,
    .bcdDevice = 0x0100,

    .iManufacturer = 0x01,
    .iProduct = 0x02,
    .iSerialNumber = 0x00,

    .bNumConfigurations = 0x01
};

uint8_t const desc_hid_report[] = {
    0x05, 0x01,                 // USAGE_PAGE (Generic Desktop)
    0x09, 0x02,                 // USAGE (Mouse)
    0xa1, 0x01,                 // COLLECTION (Application)
    0x09, 0x01,                 //   USAGE (Pointer)
    0xA1, 0x00,                 //   COLLECTION (Physical)
//  0x85, 0x01,                 //     REPORT_ID (1)
    0x05, 0x09,                 //     USAGE_PAGE (Button)
    0x19, 0x01,                 //     USAGE_MINIMUM (1)
    0x29, 0x08,                 //     USAGE_MAXIMUM (8)
    0x15, 0x00,                 //     LOGICAL_MINIMUM (0)
    0x25, 0x01,                 //     LOGICAL_MAXIMUM (1)
    0x95, 0x08,                 //     REPORT_COUNT (8)
    0x75, 0x01,                 //     REPORT_SIZE (1)
    0x81, 0x02,                 //     INPUT (Data,Var,Abs)
    0x05, 0x01,                 //     USAGE_PAGE (Generic Desktop)
    0x09, 0x30,                 //     USAGE (X)
    0x09, 0x31,                 //     USAGE (Y)
    0x16, 0x00, 0x80,           //     LOGICAL_MINIMUM(-32768)
    0x26, 0xff, 0x7f,           //     LOGICAL_MAXIMUM(32767)
    0x75, 0x10,                 //     REPORT_SIZE (16)
    0x95, 0x02,                 //     REPORT_COUNT (2)
    0x81, 0x06,                 //     INPUT (Data,Var,Rel)
    0xC0,                       //   END_COLLECTION
    0xC0,                       // END COLLECTION
};

#define CONFIG_TOTAL_LEN (TUD_CONFIG_DESC_LEN + TUD_HID_DESC_LEN)
#define EPNUM_HID 0x81

uint8_t const desc_configuration[] = {
    // Config number, interface count, string index, total length, attribute, power in mA
    TUD_CONFIG_DESCRIPTOR(1, 1, 0, CONFIG_TOTAL_LEN, 0, 100),

    // Interface number, string index, protocol, report descriptor len, EP In address, size & polling interval
    TUD_HID_DESCRIPTOR(0, 0, HID_ITF_PROTOCOL_NONE, sizeof(desc_hid_report), EPNUM_HID, CFG_TUD_HID_EP_BUFSIZE, 1)
};

char const *string_desc_arr[] = {
    (const char[]) {0x09, 0x04},        // 0: is supported language is English (0x0409)
    "Trackball",                // 1: Manufacturer
    "Trackball",                // 2: Product
};

// HID report
typedef struct __attribute__ ((packed)) {
    uint8_t buttons;
    int16_t dx;
    int16_t dy;
} hid_report_t;

hid_report_t report;

void hid_task(void) {
    int16_t dx;
    int16_t dy;

    if (!tud_hid_ready()) {
        return;
    }

    pmw3360_get_deltas(&dx, &dy);

    report.dx = dx;
    report.dy = -dy;

    uint8_t buttons = 0;
    if (!gpio_get(PIN_LMB) || !gpio_get(PIN_LEFT_CLICK)) buttons |= 0x01;
    if (!gpio_get(PIN_RMB) || !gpio_get(PIN_RIGHT_CLICK)) buttons |= 0x02;
    if (!gpio_get(PIN_MIDDLE_CLICK)) buttons |= 0x04;
    if (!gpio_get(PIN_LEFT_FUNCT_CLICK)) buttons |= 0x08;
    if (!gpio_get(PIN_RIGHT_FUNCT_CLICK)) buttons |= 0x10;
    if (!gpio_get(PIN_CENTER_FUNCT_1_CLICK)) buttons |= 0x20;
    if (!gpio_get(PIN_CENTER_FUNCT_2_CLICK)) buttons |= 0x40;

    report.buttons = buttons;

    tud_hid_report(0, &report, sizeof(report));
}

void pin_init(uint pin) {
    gpio_init(pin);
    gpio_set_dir(pin, GPIO_IN);
    gpio_pull_up(pin);
}

void pins_init(void) {
    pin_init(PIN_LMB);
    pin_init(PIN_RMB);
    pin_init(PIN_CENTER_FUNCT_1_CLICK);
    pin_init(PIN_CENTER_FUNCT_2_CLICK);
    pin_init(PIN_RIGHT_CLICK);
    pin_init(PIN_RIGHT_FUNCT_CLICK);
    pin_init(PIN_LEFT_CLICK);
    pin_init(PIN_LEFT_FUNCT_CLICK);
    pin_init(PIN_MIDDLE_CLICK);
}

void report_init(void) {
    memset(&report, 0, sizeof(report));
}

int main(void) {
    stdio_init_all();
    board_init();
    pins_init();
    pmw3360_init();
    report_init();
    tusb_init();

    pmw3360_set_cpi(800);

    while (1) {
        tud_task();             // tinyusb device task
        hid_task();
    }

    return 0;
}

// Invoked when received GET DEVICE DESCRIPTOR
// Application return pointer to descriptor
uint8_t const *tud_descriptor_device_cb(void) {
    return (uint8_t const *) &desc_device;
}

// Invoked when received GET HID REPORT DESCRIPTOR
// Application return pointer to descriptor
// Descriptor contents must exist long enough for transfer to complete
uint8_t const *tud_hid_descriptor_report_cb(uint8_t itf) {
    return desc_hid_report;
}

// Invoked when received GET_REPORT control request
// Application must fill buffer report's content and return its length.
// Return zero will cause the stack to STALL request
uint16_t tud_hid_get_report_cb(uint8_t itf, uint8_t report_id, hid_report_type_t report_type, uint8_t * buffer, uint16_t reqlen) {
    return 0;
}

// Invoked when received SET_REPORT control request or
// received data on OUT endpoint ( Report ID = 0, Type = 0 )
void tud_hid_set_report_cb(uint8_t itf, uint8_t report_id, hid_report_type_t report_type, uint8_t const *buffer, uint16_t bufsize) {
}

// Invoked when received GET CONFIGURATION DESCRIPTOR
// Application return pointer to descriptor
// Descriptor contents must exist long enough for transfer to complete
uint8_t const *tud_descriptor_configuration_cb(uint8_t index) {
    return desc_configuration;
}

static uint16_t _desc_str[32];
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

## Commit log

2025-01-13 V1 prebuild
    [Trackball.kicad_pcb, Trackball.kicad_sch]
2025-01-13 changement wroom 2 a 1
    [Trackball.kicad_pcb, Trackball.kicad_sch]
2025-01-14 ajoute pin reset capteur optique
    [Trackball-B_Cu.gbl, Trackball-B_Mask.gbs, Trackball-B_Paste.gbp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]
2025-01-14 ajout test pad
    [Trackball.kicad_pcb, Trackball.kicad_sch]
2025-01-15 re-asignement des pins gpio
    [Trackball.kicad_pcb, Trackball.kicad_sch]
2025-01-15 update markdown
    [Trackball-B_Cu.gbl, Trackball-B_Mask.gbs, Trackball-B_Paste.gbp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]
2025-01-16 changement empreinte bouton en\gpio0
    [Trackball.kicad_pcb, Trackball.kicad_sch]
2025-02-02 Passage a une molette standard et ajout circuit TP4056
    [Trackball-B_Cu.gbl, Trackball-B_Fab.gbr, Trackball-B_Mask.gbs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]
2025-02-03 changement de taille
    [Trackball.kicad_pcb, Trackball.kicad_sch]
2025-02-11 next routing try
    [Trackball.kicad_pcb, Trackball.kicad_sch]
2025-05-26 clean up for print test
    [BOM-Trackball.csv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]
2025-12-16 fist POC
    [MaSe.kicad_pcb, Unnamed.FCStd, Unnamed1.FCStd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]
2025-12-16 3d ajustement
    [Unnamed1.FCStd]
